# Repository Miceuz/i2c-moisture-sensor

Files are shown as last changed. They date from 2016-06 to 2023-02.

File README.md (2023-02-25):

# i2c-moisture-sensor

I2C based soil moisture sensor. A continuation of the [Chirp - plant watering alarm](https://github.com/Miceuz/PlantWateringAlarm) project. There is also an [RS485](https://github.com/Miceuz/rs485-moist-sensor) and an [analog](https://github.com/Miceuz/soil-moisture-sensor-analog) version available.



## I2C protocol
Available registers for reading and writing.

  Name | Register | R/W | Data length 
-------|----------|-----|-------------
GET_CAPACITANCE   | 0x00 | (r) | 2
SET_ADDRESS       | 0x01 | (w) | 1
GET_ADDRESS       | 0x02 | (r) | 1
MEASURE_LIGHT     | 0x03 | (w) | 0
GET_LIGHT         | 0x04 | (r) | 2
GET_TEMPERATURE   | 0x05 | (r) | 2
RESET             | 0x06 | (w) | 0
GET_VERSION       | 0x07 | (r) | 1
SLEEP             | 0x08 | (w) | 0
GET_BUSY          | 0x09 | (r) | 1

GET_BUSY returns 1 if any measurement is in progress, 0 otherwise.

## How to interpret the readings

16bit values are returned most significant byte first.

Both light and moisture sensors give relative values. Meaning, more moisture will give you higher reading, more light, lower reading. They are not calibrated to any particular si units - this is up to you.

Moisture is somewhat linear. I test all sensors before shipping and they give about 290 - 310 in free air at 5V supply.

Temperature is in Celsius, value is in tenths of degrees Celsius. I.e. value 252 would mean 25.2°C.

I didn't measure linearity of the light sensor, it gives 65535 in a dark room away form desk lamp. When it's dark, it takes longer to measure light, reading the light register while measurement is in progress will return the previous reading. Be aware, light sensor is pretty noisy.

Temperature is measured by the thermistor on the body of the sensor. Calculated absolute measurement accuracy is better than 2%. 

Note Upon reading the moisture or temperature value, a value form the previous read command is returned and the new measurement is started. If you do rare measurements and want to act instantly, do two consecutive readings to get the most up to date data. Also you can read GET_BUSY register via i2c - it will indicate when the measurement is done. Basically the process goes like this: read from GET_CAPACITANCE, discard results, then read from GET_BUSY until you get '0' as an answer, then read form GET_CAPACITANCE again - the returned value is the soil moisture NOW.

### Python library for Raspberry Pi

*NOTE: if you experience problems on Raspberry Pi 3, slow down I2C bus speed by adding this line to /boot/config.txt:*
**dtparam=i2c1_baudrate=30000**

[Göran Lundberg](https://github.com/ageir) has released a Python library for Raspberry Pi: [https://github.com/ageir/chirp-rpi](https://github.com/ageir/chirp-rpi)
It has a very comprehensive documentation and covers a lot of functionality.

Some features:
* Uses a trigger function to trigger all enabled sensors. User selectable.
* Get soil moisture in percent (requires calibration) or capacitance value.
* Several temperature scales to choose from. Celcius, Fahrenheit and Kelvin.
* Offset to calibrate the temperature sensor.
* Measurement timestamps for all on board sensors.
* Built in support for changing the I2C address of the sensor.
* Deep sleep mode to conserve power.
* Calibration tool for soil moisture.

### Raspberry Pi examples

This is interface class provided by Daniel Tamm and Jasper Wallace
```python
#!/usr/bin/python
# cannot use python3 because smbus not working there
# Modified script from https://github.com/JasperWallace/chirp-graphite/blob/master/chirp.py
# by DanielTamm

import smbus, time, sys

class Chirp:
	def __init__(self, bus=1, address=0x20):
		self.bus_num = bus
		self.bus = smbus.SMBus(bus)
		self.address = address
    
	def get_reg(self, reg):
		# read 2 bytes from register
		val = self.bus.read_word_data(self.address, reg)
		# return swapped bytes (they come in wrong order)
		return (val >> 8) + ((val & 0xFF) << 8)

	def reset(self):
		# To reset the sensor, write 6 to the device I2C address
		self.bus.write_byte(self.address, 6)

	def set_addr(self, new_addr):
		# To change the I2C address of the sensor, write a new address
		# (one byte [1..127]) to register 1; the new address will take effect after reset
		self.bus.write_byte_data(self.address, 1, new_addr)
		# second request is required since FW 0x26 to protect agains spurious address changes
		self.bus.write_byte_data(self.address, 1, new_addr)
		self.reset()
		self.address = new_addr

	def moist(self):
		# To read soil moisture, read 2 bytes from register 0
		return self.get_reg(0)

	def temp(self):
		# To read temperature, read 2 bytes from register 5
		return self.get_reg(5)

	def light(self):
		# To read light level, start measurement by writing 3 to the
		# device I2C address, wait for 3 seconds, read 2 bytes from register 4
		self.bus.write_byte(self.address, 3)
		time.sleep(1.5)
		return self.get_reg(4)

	def __repr__(self):
		return "<Chirp sensor on bus %d, addr %d>" % (self.bus_num, self.address)

if __name__ == "__main__":
	addr = 0x20
	if len(sys.argv) == 2:
		if sys.argv[1].startswith("0x"):
			addr = int(sys.argv[1], 16)
		else:
			addr = int(sys.argv[1])
	chirp = Chirp(1, addr)

	print chirp
	print "Moisture\tTemperature\tBrightness"
	while True:
		print "%d\t%d\t%d" % (chirp.moist(), chirp.temp(), chirp.light())
		time.sleep(1)
```

This is another RasPi example provided by user *krikk*
```python
#!/usr/bin/python

#https://github.com/adafruit/Adafruit-Raspberry-Pi-Python-Code/tree/master/Adafruit_I2C
from Adafruit_I2C import Adafruit_I2C
from time import sleep, strftime
from datetime import datetime
deviceAddr = 0x20

i2c = Adafruit_I2C( deviceAddr, -1, False )

#to change adress
#i2c.write8( 1, 0x22 )

#reset sensor, we need this otherwise i get inconsistent light reading in the dark...
i2c.write8( deviceAddr, 0x06 )
sleep(5)

i2c.write8(deviceAddr, 3)
sleep(3)
light = i2c.readU16(4, False)
temp = i2c.readS16(5, False)/float(10)
moisture = i2c.readU16(0, False)
print "Temperature\tMoisture\tBrightness"
print str(temp) + ":" + str(moisture) + ":" + str(light)
```

### Arduino library
Ingo Fischer has written an Arduino library for the sensor, it has a couple of ready made examples: https://github.com/Apollon77/I2CSoilMoistureSensor 

Below are old examples for bare-bones Arduino illustrating a basic I2C use.

### Arduino example
```arduino
#include <Wire.h>

void writeI2CRegister8bit(int addr, int value) {
  Wire.beginTransmission(addr);
  Wire.write(value);
  Wire.endTransmission();
}

unsigned int readI2CRegister16bit(int addr, int reg) {
  Wire.beginTransmission(addr);
  Wire.write(reg);
  Wire.endTransmission();
  delay(20);
  Wire.requestFrom(addr, 2);
  unsigned int t = Wire.read() << 8;
  t = t | Wire.read();
  return t;
}

void setup() {
  Wire.begin();
  Serial.begin(9600);
  writeI2CRegister8bit(0x20, 6); //reset
}

void loop() {
  Serial.print(readI2CRegister16bit(0x20, 0)); //read capacitance register
  Serial.print(", ");
  Serial.print(readI2CRegister16bit(0x20, 5)); //temperature register
  Serial.print(", ");
  writeI2CRegister8bit(0x20, 3); //request light measurement 
  Serial.println(readI2CRegister16bit(0x20, 4)); //read light register
}
```
### Note for ESP8266 based systems
In some cases the default ESP8266 Arduino I2C library has the clock stretching timeout set too low. If you experience intermittent communication, add this to your code:
```
Wire.setClockStretchLimit(2500)
```
### Micropython
Micropython library is available here: [https://github.com/scopelemanuele/pyChirpLib](https://github.com/scopelemanuele/pyChirpLib)

## Address change example
By default the sensor comes with 0x20 set as an address, this is an example on how to change address for indivitual sensor:
```arduino
#include <Wire.h>
 
void writeI2CRegister8bit(int addr, int reg, int value) {
  Wire.beginTransmission(addr);
  Wire.write(reg);
  Wire.write(value);
  Wire.endTransmission();
}
 
void writeI2CRegister8bit(int addr, int value) {
  Wire.beginTransmission(addr);
  Wire.write(value);
  Wire.endTransmission();
}
 
void setup() {
  Wire.begin();
  Serial.begin(9600);
                                       //talking to the default address 0x20
  writeI2CRegister8bit(0x20, 1, 0x21); //change address to 0x21
  writeI2CRegister8bit(0x20, 6);       //reset
  delay(1000);                         //give it some time to boot
}
 
/*loop scans I2C bus and displays foud addresses*/ 
void loop()
{
  byte error, address;
  int nDevices;
 
  Serial.println("Scanning...");
 
  nDevices = 0;
  for(address = 1; address < 127; address++ )
  {
    // The i2c_scanner uses the return value of
    // the Write.endTransmisstion to see if
    // a device did acknowledge to the address.
    Wire.beginTransmission(address);
    error = Wire.endTransmission();
 
    if (error == 0)
    {
      Serial.print("I2C device found at address 0x");
      if (address<16)
        Serial.print("0");
      Serial.print(address,HEX);
      Serial.println("  !");
 
      nDevices++;
    }
    else if (error==4)
    {
      Serial.print("Unknow error at address 0x");
      if (address<16)
        Serial.print("0");
      Serial.println(address,HEX);
    }    
  }
  if (nDevices == 0)
    Serial.println("No I2C devices found\n");
  else
    Serial.println("done\n");
 
  delay(5000);           // wait 5 seconds for next scan
}
```
### Particle Photon

There is a great [tutorial](ParticlePhoton-tutorial.md) by Miriam Cox for Particle Photon boards. Also there is a [library available](https://github.com/VintageGeek/I2CSoilMoistureSensor) by Mike.

## Links and mentions

* A [video from Growing Robot](https://www.youtube.com/watch?v=rB4vS7I0euA) about using the sensors with Raspberry Pi
* A [complete Open Source logging solution](https://git.jeelabs.org/jcw/zelkova) employing a batch of 40 sensors in Crete for tree monitoring
* [Chirp - Wemos - Azure bridge](https://github.com/korpiq/chirp-wemos-meter) ESP8266 based system that pushes sensor data to Azure cloud serivices.

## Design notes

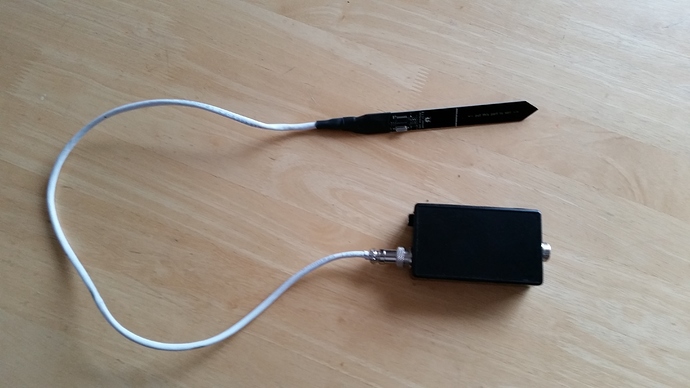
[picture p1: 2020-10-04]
pics/esp-8266-.jpg

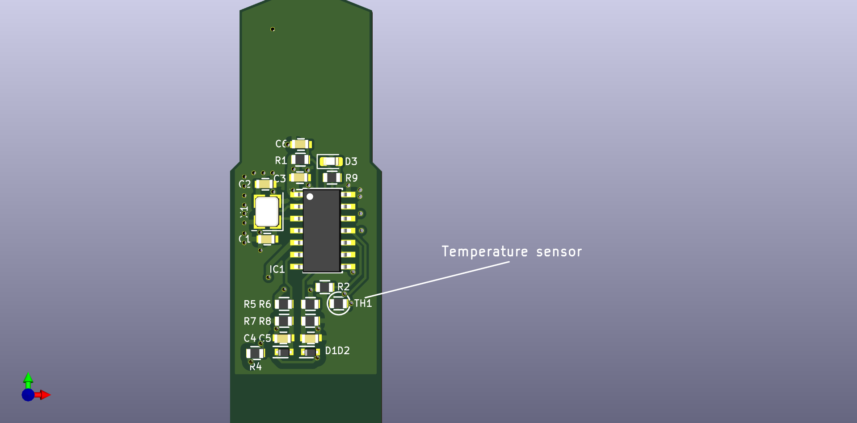
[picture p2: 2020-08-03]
temp-sensor-position.png

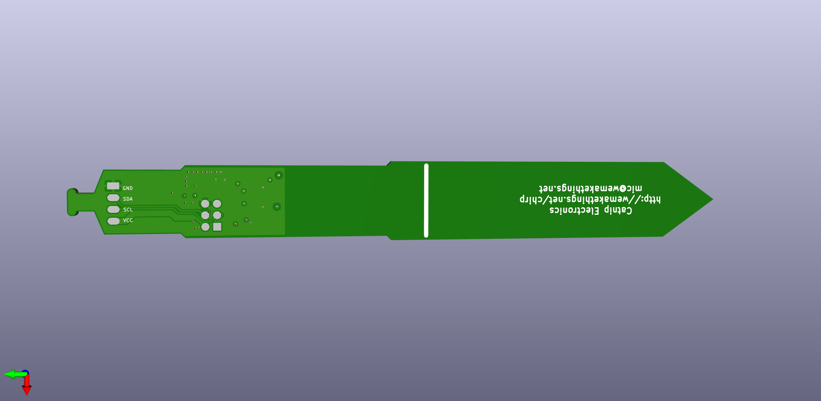
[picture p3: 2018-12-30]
i2c-moist-sensor.png

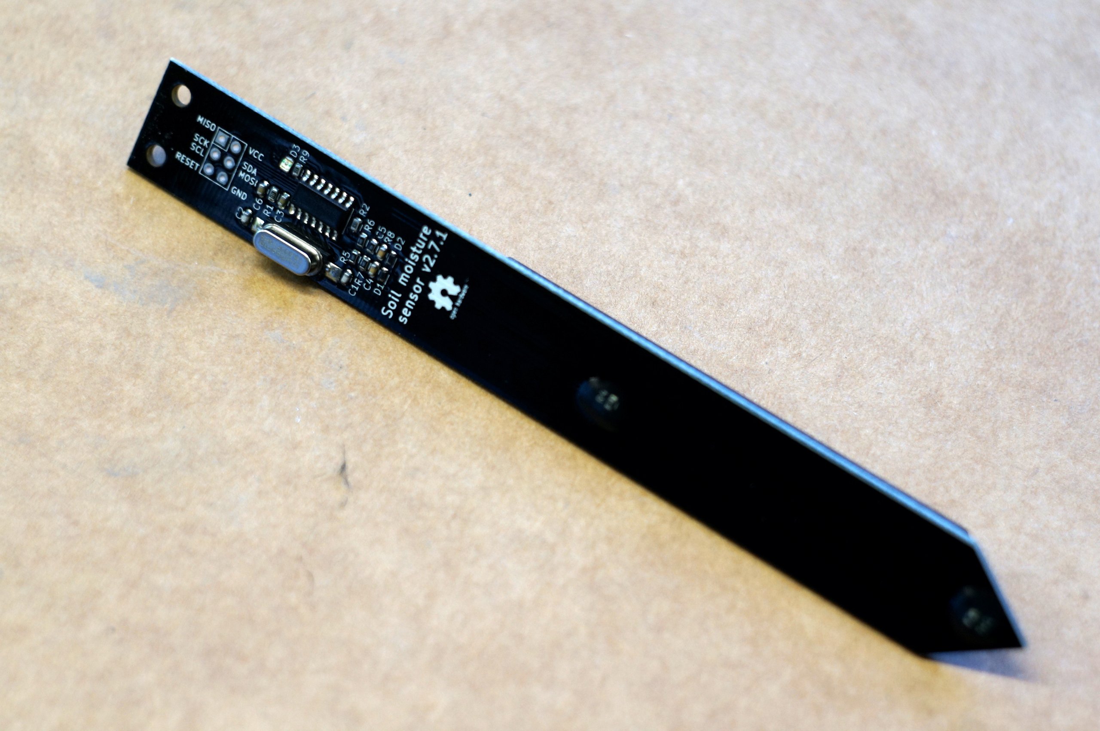
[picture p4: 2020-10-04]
pics/i2c-sensor-v2.7.1.jpg

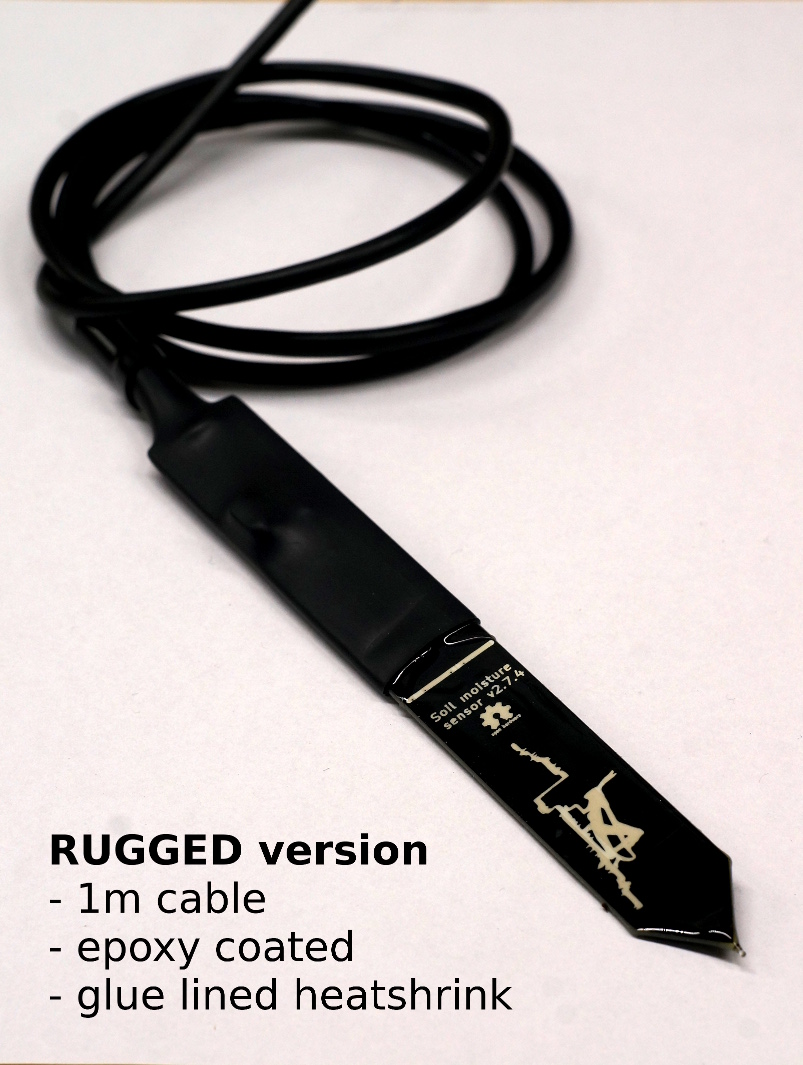
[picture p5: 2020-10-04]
pics/rugged.jpg

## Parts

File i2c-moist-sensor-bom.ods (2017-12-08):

ID | Designator | Value | Qty | FarnellID | Manufacturer | Mfg # | Replacement options
1 | IC1 | Attiny441 | 1 | 2396717 | ATMEL | ATTINY441-SSU | Exact part as specified
2 | D1, D2 | RB521S30T1G | 2 | 2322476 | FAIRCHILD SEMICONDUCTOR | BAT54XV2 | Exact part as specified
3 | TH1 | NCP18XH103F03RB | 1 | 2456122 | MURATA | NCP18XH103F03RB | Exact part as specified
4 | R1 | 10k | 1 | 2379939 | PANASONIC ELECTRONIC COMPONENTS | ERJ3RBD1002V | Any 10k resistor
5 | R2 | 10k 0.5% | 1 | 2379939 | PANASONIC ELECTRONIC COMPONENTS | ERJ3RBD1002V | Exact part as specified
6 | X1 | 16MHz | 1 | 2395958 | MULTICOMP | MCRSD16000F183000RR | Exact part as specified
7 | C1, C2 | 33pF | 2 | 2310585 | MULTICOMP | MC0603N330J500CT | Any 33pF capacitor
8 | R4, R9 | 330R | 2 | 2446656 | MULTICOMP | MCWR06X3300FTL | Any 5% 330R resistor
9 | C3, C6 | 1u 10V | 2 | 2310637 | MULTICOMP | MC0603X105K100CT | Any 1u capacitor
10 | C4, C5 | 1n | 2 | 2310598 | MULTICOMP | MC0603B102K500CT | Any 1n capacitor
11 | R5, R6, R7, R8 | 1M | 4 | 2446602 | MULTICOMP | MCWR06X1004FTL | Any 1M resistor
12 | D3 | KP-1608SURCK | 1 | 2449786 | KINGBRIGHT | KP-1608SURCK | Any 2V Vf 0603 LED
13 | HEATSHRINK |  | 1 |  |  | CB-DWT16-4X/1M-BK

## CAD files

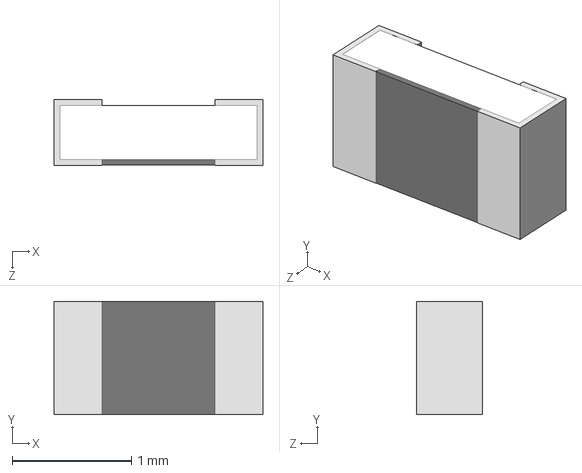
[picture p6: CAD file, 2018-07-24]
3d/User Library-RES_SMD-1.STEP
1.75 x 0.95 x 0.55 mm

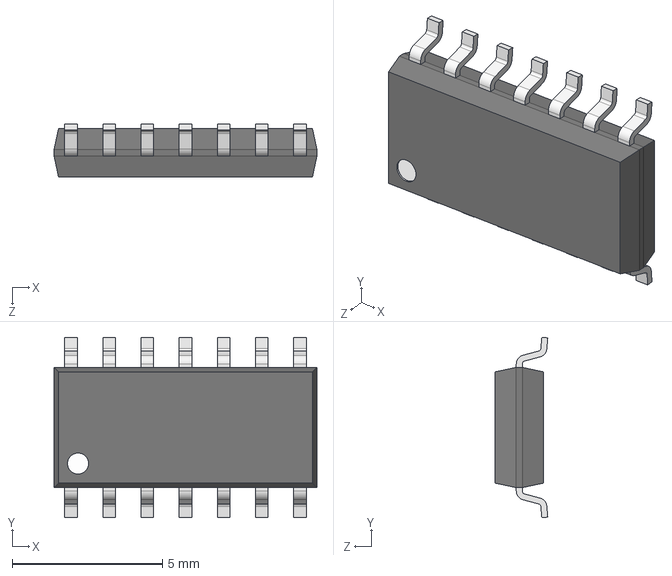
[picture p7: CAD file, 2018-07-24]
3d/User Library-SOIC-14.STEP
8.75 x 6.00 x 1.75 mm

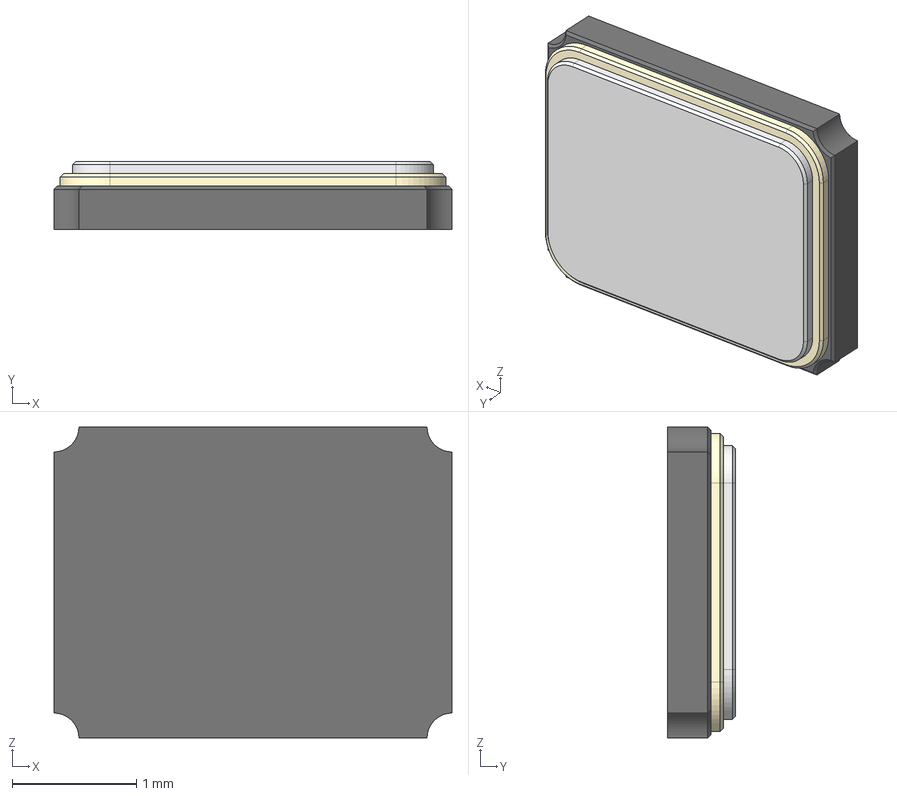
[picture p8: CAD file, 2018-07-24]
3d/CRY_SMD3225.STEP
3.20 x 0.55 x 2.50 mm

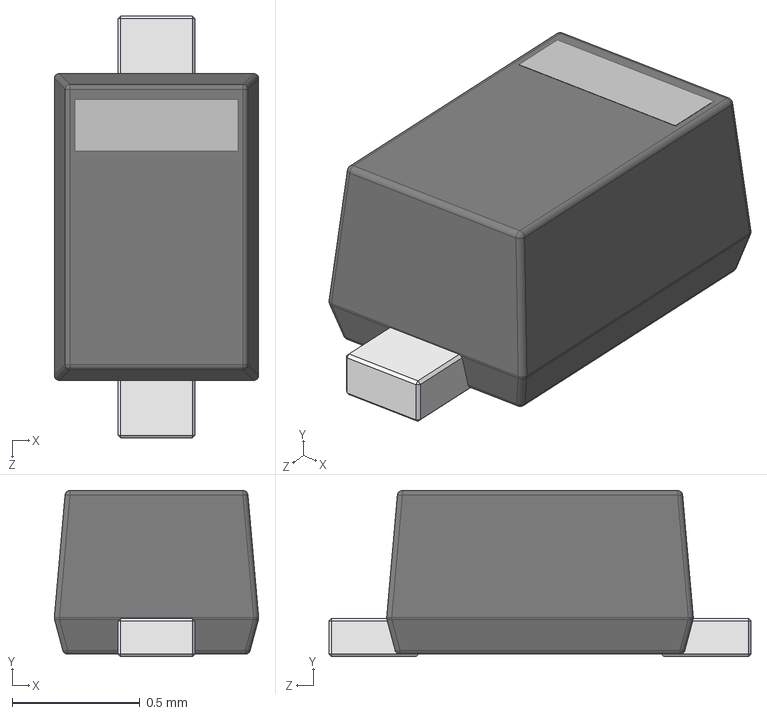
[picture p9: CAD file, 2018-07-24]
3d/User Library-SOD523-2.STEP
0.8 x 0.651 x 1.65 mm

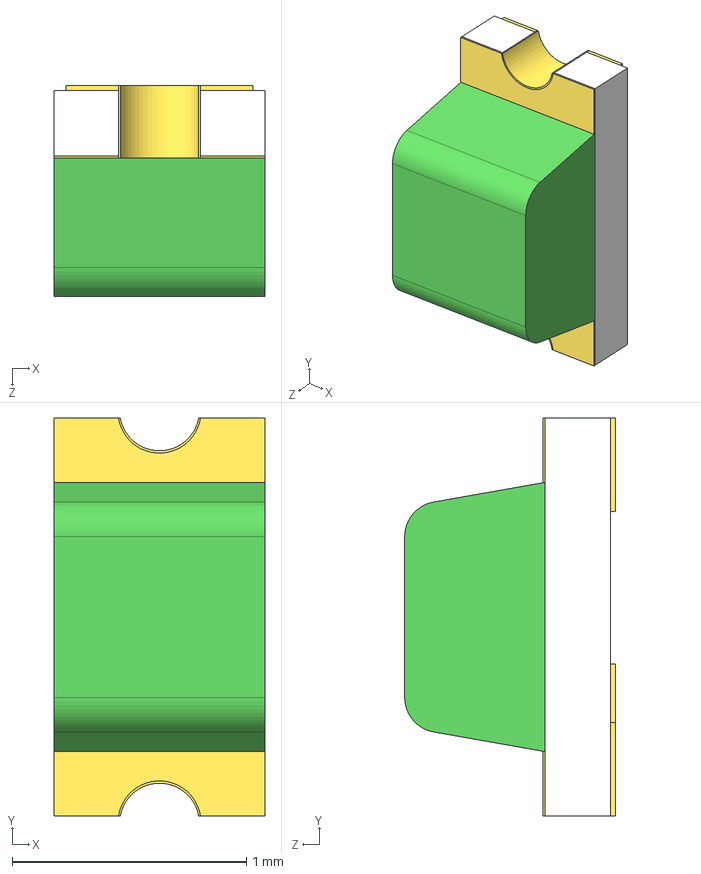
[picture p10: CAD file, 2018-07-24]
3d/User Library-LTST-C190GKT.STEP
0.9 x 1.70 x 0.9 mm
User Library-LTST-C190GKT_Pad005
User Library-LTST-C190GKT_Pad001
User Library-LTST-C190GKT_Pad004
User Library-LTST-C190GKT_Pad003
User Library-LTST-C190GKT_Lens
User Library-LTST-C190GKT_Pad

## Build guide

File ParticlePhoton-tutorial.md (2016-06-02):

Getting sensor to work with Particle Photon
===========================================
by Miriam Cox

As someone completely new to electrical work and to Particle microcontrollers, I hit a few slight hurdles in trying to convert this. For anyone else interested in how I got the sensor working with a Particle Photon, it's pretty simple:

**1) STARTING YOUR PROJECT**
Copy the example code into a "New App" in your Particle.io web IDE. You can name it whatever you'd like. Make sure you ALSO have your Particle Photon microcontroller registered to your Particle account so that you can flash the project onto it.

**2) ADDING A LIBRARY**
Create a new file inside this new app, then name it according to the library you are using (I eventually used Apollon77's code, as suggested by Miceuz) and copy the appropriate code from its git repo into these new files. Don't forget to include the library in your app's main file using the following syntax:
#include "NameOfLibraryFile.h"

_Note: As of this writing, it is also possible to fork this repo and rewrite it for import as a library into your Particle app, but that is a bit more work._

**3) INCLUDES**
In any library or example files you added to your project, strip out "define if/else" statements and their contents, then replace them with the following line (which will add Wire library and device functionality):
**#include "Particle.h"**

Flash your Photon with this app. Assuming you are successful (and assuming you also have the particle software installed on your computer) you can then open up a command line prompt on your computer and enter this command to view the serial monitor output from the Photon:
**particle serial monitor**

**4) SOLDERING**
For prototyping, I unplugged the Photon (which had headers), then popped it onto a breadboard. Then I stripped some jumper wires and soldered them directly to the I2C sensor's SCK/SCL line, VCC line, GND line, and SDA/MOSI line.

Obviously, you need to connect the Photon to your sensor; so to take advantage of the I2C capabilities of the Photon, you'll need to connect the Photon's D1 input to the sensor's SCK/SCL (clock) output, and then connect the Photon's D0 input to the sensor's SDA (data) output on the breadboard. Connect the sensor's VCC line and the Photon's 3V3 (power) input together on the breadboard. Then connect the sensor's GND line and the Photon's GND (ground) lines together on the breadboard.

**VERY IMPORTANT:** You will also need "pull up resistors" on the clock and the data lines; initially, I had NO IDEA what this meant, but, it turns out you'll just connect those lines into the power line using a resistor. All I had to do was grab a resistor and connect one leg of it to the SDA/MOSI-D0 line via the breadboard, then the other leg to the VCC-3V3 (power) line on the breadboard. Then I did the same for the clock, connecting one leg of the resistor to the SCK/SCL-D1 line and the other to the VCC-3V3 line.

_Note: in my case, all I had were 200 ohm resistors, and these at least got my project working. If you don't have any resistors connected, then your particle serial monitor won't even recognize that the I2C sensor is connected. Readings on the web suggest that ideally, you should use somewhere between a 4.7k ohm and 10k ohm resistor for each pull up, to help prevent "drift" on your readings, but someone more electrically inclined than myself could explain/clarify this._

I hope this helps! This sensor is absolutely FANTASTIC, by the way. Very sensitive (which I like), uses capacitive reading (which is much more accurate), and easy to use. Happy DIYing, friends!

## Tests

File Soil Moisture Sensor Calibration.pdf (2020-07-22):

I2C Soil Moisture Sensor Calibration (Catnip Electronics)
Converting the raw capacitance values of the soil moisture sensors to dry basis moisture content (%) of the soil

Materials and Methods

- Soil moisture sensor was powered at 3V3,
- Soil sample was collected from the field (Niato),
- Soil sample was sieved (2 mm) and cleaned from stones and roots,
- Soil sample was placed in the oven at 105oC for 24 hours,
- After 24 hours, when the soil was completely oven dried, the soil sample was removed from the oven and placed in an aluminum disk (23x17x6 cm),
- The weight of the empty disk and the dry soil were measured on an analytical balance,
- Three soil moisture sensors were buried in the soil,
- The aluminum disk containing the dry soil and the three soil moisture sensors was placed on an analytical balance,
- The sample weight (aluminum disk containing the dry soil and the three soil moisture sensors) was recorded,
- The raw capacitance values from the three soil moisture sensors were also recorded (completely dry soil),
- Distilled water was added to the dry soil until full saturation. Water was added evenly throughout the aluminum disk. This is critically important to ensure that moisture is thoroughly and evenly spread through the entire sample and not clumped at the surface or some other location (Picture 1),
- Balance readings of the sample weight (aluminum disk containing the wet soil and the three soil moisture sensors) and the raw capacitance values from the three soil moisture sensors were recorded simultaneously at an interval of 30 minutes for 26 days at room temperature (Picture 2),

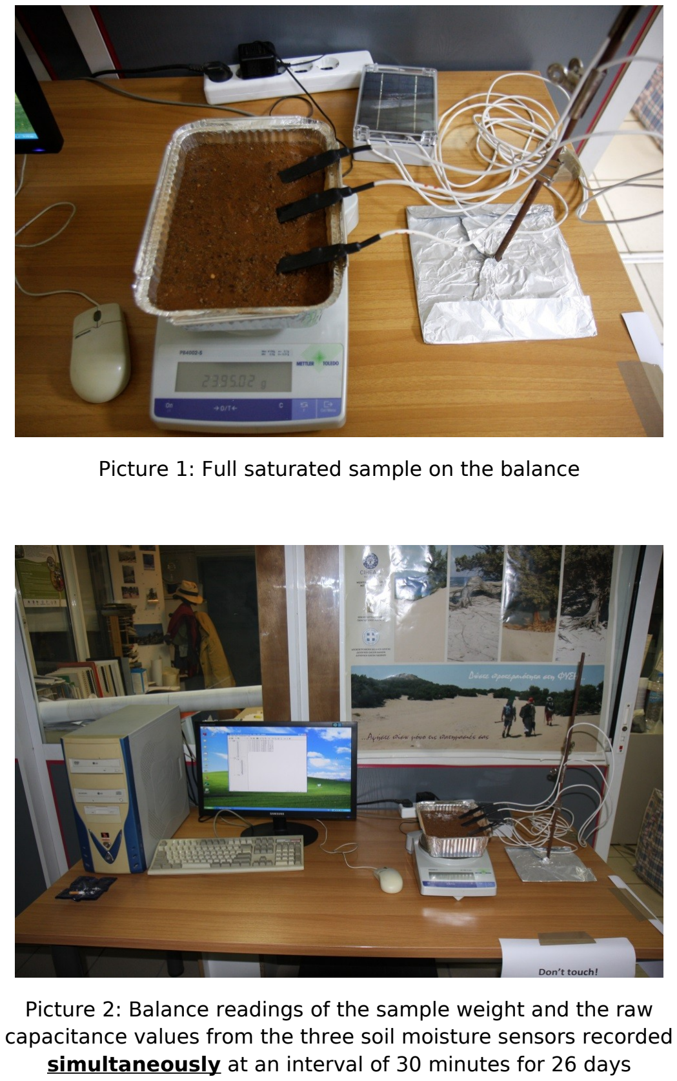
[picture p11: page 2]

Picture 1: Full saturated sample on the balance

Picture 2: Balance readings of the sample weight and the raw capacitance values from the three soil moisture sensors recorded simultaneously at an interval of 30 minutes for 26 days

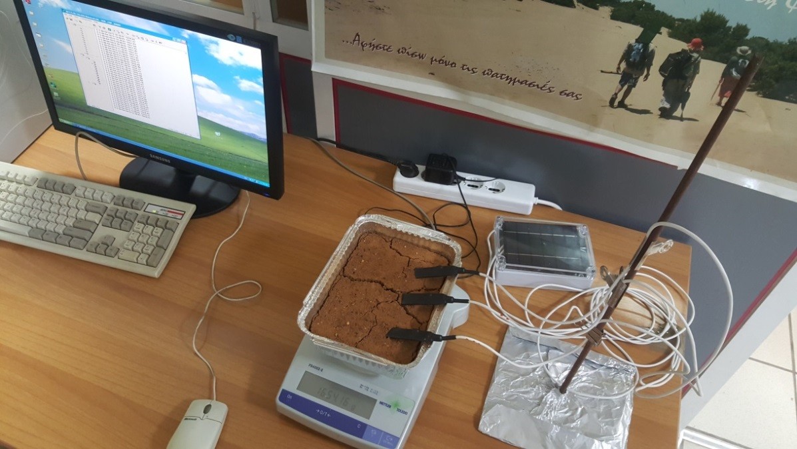
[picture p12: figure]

Picture 3: Dry sample after 26 days - balance readings of the sample weight and the raw capacitance values from the three soil moisture sensors recorded simultaneously at an interval of 30 minutes

- The real dry basis moisture content (MCd) of the soil sample at 30 minutes interval was calculated as:

MCd = (Wet soil weight – Dry soil weight) / Dry soil weight

- Having the real dry basis moisture content of the soil sample and the readings of its corresponding raw capacitance values from the three soil moisture sensors (30 minutes interval), the following 2
nd

order polynomial equation was developed using regression analysis in Excel:
MCd = (0.000001007*X²
)+(0.000024885*X)-
0.062508722

Where MCd is the calculated dry basis moisture content of the soil sample and X is the average readings of the soil moisture sensors.

SUMMARY OUTPUT

Regression Statistics
Multiple R | 0,997707255
R Square | 0,995419766
Adjusted R Square | 0,995410093
Standard Error | 0,007208576
Observations | 950

ANOVA
| df | SS | MS | F | Significance F
Regression | 2 | 10,69467422 | 5,347337 | 102905,5 | 0
Residual | 947 | 0,049209503 | 5,2E-05
Total | 949 | 10,74388372
| Coefficients | Standard Error | t Stat | P-value | Lower 95% | Upper 95% | Lower 95,0% | Upper 95,0%
Intercept | -0,062508722 0,005054067 | -12,368 | 1,12E-32 | -0,072427189 | -0,052590256 | -0,072427189 | -0,052590256
X | 0,000024885 | 2,43462E-05 | 1,022122 | 0,306984 | -2,2894E-05 | 7,26635E-05 | -2,2894E-05 | 7,26635E-05
X
2 | 0,000001007 | 2,7467E-08 | 36,67815 | 5,5E-184 | 9,53536E-07 | 1,06134E-06 | 9,53536E-07 | 1,06134E-06

Figure 1: Excel summary output of the regression

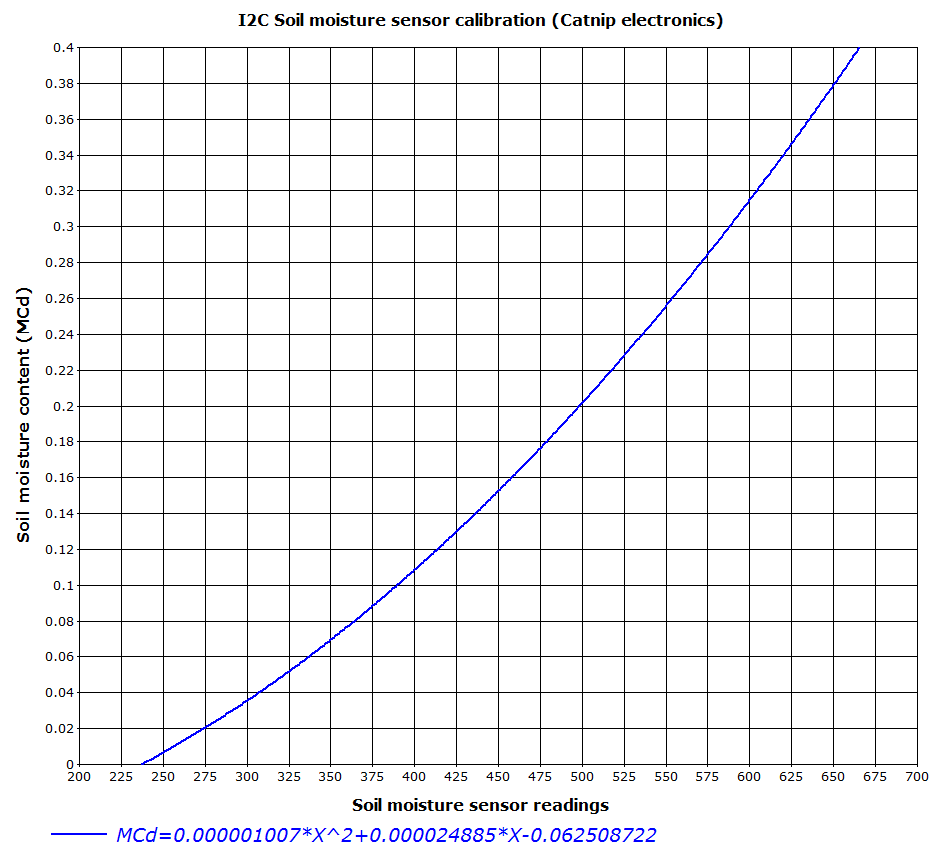
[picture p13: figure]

Figure 2: Graph of the polynomial equation

The developed equation can be used in Excel using the following formula:

=(0,000001007*A2^2)+(0,000024885*A2)-0,062508722

Where A2 is the cell containing the soil moisture sensor raw capacitance reading

Example:

The calculated dry basis moisture content (MCd) of the soil when a soil moisture sensor reads a capacitance value of 550 corresponds to:

MCd = (0.000001007*550²

)+(0.000024885*550)-0.062508722

MCd = 0.2558 or 25.58 %

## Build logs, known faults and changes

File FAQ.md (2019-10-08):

# Frequently asked questions

**Do you have the exact dimensions, or even better a CAD drawing of the sensor in 3D?**

Sensors are 18mm x 149mm. Zipped step file is available in github repository.

**How to set up multiple sensors connected to one Arduino Uno?**

You can connect several sensors to a single I2C bus. Exact maximum amount depends on many factors, mostly on the wiring length. To have several sensors working on a bus, you have to assing an individual address to each sensor. To do that, connect each sensor one by one and run an address change routine. Code is available as [an example](https://github.com/Apollon77/I2CSoilMoistureSensor/blob/master/examples/ChangeSensorI2CAddress/ChangeSensorI2CAddress.ino) of Arduino library. Raspberry Pi example is also [available](https://github.com/ageir/chirp-rpi#advanced-example-with-address-change-ability-and-calibration).

**Can I use a X meter long cable without affecting the sensor measurements?**

It depends. Note that I2C bus is not ment to run on cables, so it's a hack already. Nevertheless, a lot of products do this. I suggest reading online resources about running I2C on long cables to get some background information, but generally, to support long cables and ensure robust communication you can do the following: 
 * lower pullup resistor value, calculation is a bit complicated, but it seems you can go as low as 1k. More info [here](https://electronics.stackexchange.com/questions/1849/is-there-a-correct-resistance-value-for-i2c-pull-up-resistors).
 * slow down I2C speed. Consult your controller board documentation on how to do that
 * Use shielded cable
 
**How to solder wire to the sensor?**

Do not solder wires to the 6 pad connector - this is a programming header. Solder to 4 pads marked VCC, SCL, SDA, GND at the edge of the board. I suggest using a shielded 4 wire cable designed for security signalization installations. Do not solder the shield to the sensor, but ground it at the controller board side. Fix cable to the board using zip tie. Cover the wire connection and SMD parts with **glue-lined** heatshrink. Do not use a simple heatshrink as it will eventually let water in and will not allow it to evaporate resulting in short sensor lifetime.

**Do you offer the source code from the i2c chrip project? Can I reflash firmware of the sensor?**

Yes, sure, the sensor is open source hardware, all the code and hardware files are available on the [github page](https://github.com/Miceuz/i2c-moisture-sensor). You can use 6 pad header to program it using any AVR programming hardware like TinyISP, UsbAsp and similar. Also, you can use your [Arduino board as an AVR ISP programmer](https://www.arduino.cc/en/Tutorial/ArduinoISP).
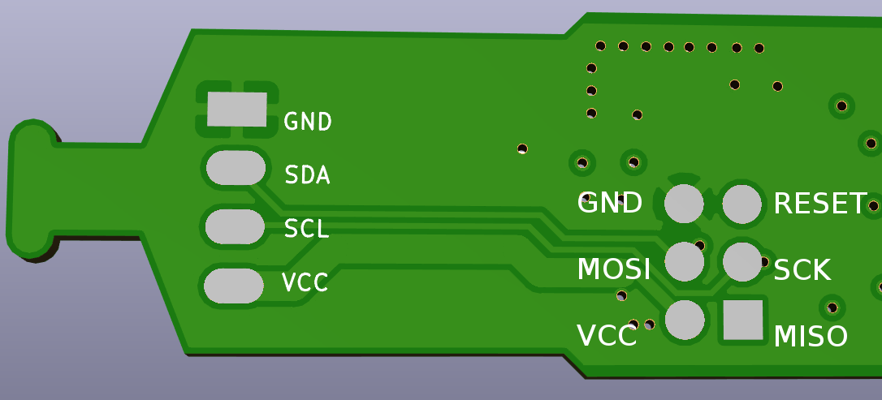
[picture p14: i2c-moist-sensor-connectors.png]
connectors


**Communication with ESP8266-based systems is unreliable, sensor sends data then stops working.**

In depth technical analysis is [available here](https://github.com/Apollon77/I2CSoilMoistureSensor/issues/8#issuecomment-295715953).

Add this call after you initialize I2C bus:
```
  Wire.setClockStretchLimit(4000); 
```

**How durable are non-rugged sensors?**

Standard solder mask seems to last about 3 months before flaking off. It really depends on the type of your soil and how often do you remove and insert the sensor as scratches will damage the surface and shorten the lifespan. I have had sensors working flawlessly for over a year in the flower pot at home when not disturbed. Note that you **must** protect sensor electronics with **glue-lined** heatshrink if you are going to install it outdoors. I use [this heatshrink](https://www.tme.eu/en/details/cb-dwt16-4x_1m-bk/heat-shrink-tubes/cyg/cb-dwt4x-160/) but you can use any similar one.

**Can you set different address for each sensor before shipping?**

Yes I can for orders of 50pcs or more, please drop me an email - mic at wemakethings net

## Rugged sensors

**How do I connect the sensor to my board?**

Wire colors go like this:
 * RED - VCC
 * BLACK - GND
 * BLUE or GREEN- SDA
 * YELLOW - SCK 

You can leave the metal sheet and metal wire unconnected for a quick test, but connect it to GND for proper installation.

Please check if your controller board has onboard pullup resistors for I2C. You need to add pull up resistors to both SCL and SDA lines if they are not there. Raspberry Pi has pullups onboard, Arduino UNO does not.

**What is the expected life of the rugged sensor for continuous use outdoor?**

I still don't have enough data to answer this question. Rugged sensors should be in practice indestructable, but failures sometimes happen. If you are using rugged sensor please let me know about the failures you experience. 

**Light sensor of rugged variant?**

Light sensing does not work for rugged sensors as light sensor is covered by heatshrink.

**I would like to have sensors with a cable up to X meters**

Sometimes I can provide customization for orders over 50 pcs, please drop me an email - mic at wemakethings net.

## Miscelaneous

**Can you provide a formal EU invoice?**

Yes, I can, please contact me directly via email - mic at wemakethings net

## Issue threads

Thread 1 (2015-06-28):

Can it be used outdoor ?

txaj, 2015-06-28:
Or even buried 5-6 cm underground ?

(I'm sorry to open an issue to ask a question but I couldn't find any way to contact you without registering on tindie)

Miceuz, 2015-06-29:
You would want to  cover in additional protection the place where cable
is soldered to the sensor, some people are putting a tube over the
electronics and pouring epoxy or silicone into it.

Regarding burying it underground - you would have to test this yourself
;) The answer would be "probabaly" after you pot it with above method.

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

--
mic.

dedekcz, 2020-04-16:
@Miceuz Nice project, Do You have any recommendation which epoxy is right one? is there any request for conductivity properties?

Miceuz, 2020-04-16:
You will get different reading with different kind of epoxy, but in general it does not matter al long as you calibrate after potting, make sure it's just non-conductive one, having no metal inside.

Closed 2015-06-29.

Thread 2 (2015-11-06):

strange reading on the light sensor & bugs in example code??

krikk, 2015-11-06:
hi!

i got your sensor running with a raspberry pi and after a lot of research and tries i got very good readings.. my raspberry pi code:

```
#!/usr/bin/python

#https://github.com/adafruit/Adafruit-Raspberry-Pi-Python-Code/tree/master/Adafruit_I2C
from Adafruit_I2C import Adafruit_I2C
from time import sleep, strftime
from datetime import datetime
deviceAddr = 0x20

i2c = Adafruit_I2C( deviceAddr, -1, False )

#to change adress
#i2c.write8( 1, 0x22 )

#reset sensor, we need this otherwise i get inconsistent light reading in the dark...
i2c.write8( deviceAddr, 0x06 )
sleep(5)

i2c.write8(deviceAddr, 3)
sleep(3)
light = i2c.readU16(4, False)
temp = i2c.readS16(5, False)/float(10)
moisture = i2c.readU16(0, False)
print str(temp) + ":" + str(moisture) + ":" + str(light)
```

... only strange thing i noted there was that i had to reset the sensor always before reading values, because otherwise i got strange readings from the light sensor after a few reads... have no clue why... buts that ok with me.

but now i got a shiny new arduino uno and i tried to run your sensor with it, and once again i get wrong readings from the light sensor, e.g. i get a negative reading when measuring in a dark room

i used the provided example code from github a adapted it:

```
void loop(){

    //Reset i2c moisture sensor
    Serial.println("Reset i2c moisture sensor");
    writeI2CRegister8bit(0x20, 6); //reset
    delay(5000);

    writeI2CRegister8bit(0x20, 3); //request light measurement
    delay(3000);
    int light = readI2CRegister16bit(0x20, 4); //read light register
    int moisture = readI2CRegister16bit(0x20, 0); //read capacitance register
    float temp = readI2CRegister16bit(0x20, 5)/(float)10; //temperature register
    char tempstr[15];
    dtostrf(temp,4, 1, tempstr);

    Serial.print("moisture: ");
    Serial.print(moisture);
    Serial.print(", Temp: ");

    Serial.print(tempstr);
    Serial.print(", Light: ");
    Serial.println(light);
    delay(2000);
}

void writeI2CRegister8bit(int addr, int value) {
    Wire.beginTransmission(addr);
    Wire.write(value);
    Wire.endTransmission();
}

unsigned int readI2CRegister16bit(int addr, int reg) {
    Wire.beginTransmission(addr);
    Wire.write(reg);
    Wire.endTransmission();
    delay(20);
    Wire.requestFrom(addr, 2);
    unsigned int t = Wire.read() << 8;
    t = t | Wire.read();
    return t;
}
```

 and i noted a few strange things in it:

```
unsigned int readI2CRegister16bit(int addr, int reg) {
...
}
```

why unsigned ?? ...what about negative temperature values (just tested with a cool-pack, give completely wrong values) (this works with my raspberry pi, python code)
also the example code does not wait 3 seconds with reading light value after writing...?

all in all the provided example code seems wrong to me... i reads values, but i think there is something wrong with the conversion of the values... would be nice if you could have a look into this  or give me some hints what i'm doing wrong... thx

Miceuz, 2015-11-13:
Hi,

I'm not exactly sure why you get weird readings. Are aware that light
measurement takes some time, if you query the sensor before reading is
done, it returns the old value. So basically you should wait for ~3 - 5
seconds before reading light measurement result.

Thanks for the code!

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

--
mic.

Apollon77, 2015-11-14:
I think you need an "Unsigned int" for the light reading ... then you will never get negaive values.

For Temperature it could work with "signed" values ... will test the next days ...

Apollon77, 2015-11-15:
I tested the sensor today in "cold" environment an git interesting "light" values - it seems that the light sernsor don't like cold :-)
I've put the sensor in my -14 degree celsius fridge ... each reading in the following list is 3 seconds delay:
At start of the test the values wew at around 236-238 capaticitance, 22,7 degree celsius and ligth around 25/26.000 as you see in the first values. Then I moved to the fridge and light was changig, but this is also not interesting. Look at the timepoint where temperature in falling ...

Soil Moisture Capacitance: 238, Temperature: 22.70, Light: 25833
Soil Moisture Capacitance: 236, Temperature: 22.70, Light: 26611
Soil Moisture Capacitance: 237, Temperature: 22.70, Light: 26522
Soil Moisture Capacitance: 237, Temperature: 22.70, Light: 26289
Soil Moisture Capacitance: 238, Temperature: 22.70, Light: 26027
Soil Moisture Capacitance: 236, Temperature: 22.70, Light: 29537
Soil Moisture Capacitance: 237, Temperature: 22.70, Light: 33503
Soil Moisture Capacitance: 237, Temperature: 22.80, Light: 33672
Soil Moisture Capacitance: 237, Temperature: 22.80, Light: 31238
Soil Moisture Capacitance: 237, Temperature: 22.60, Light: 16495
Soil Moisture Capacitance: 237, Temperature: 22.70, Light: 16924
Soil Moisture Capacitance: 237, Temperature: 22.50, Light: 18798
Soil Moisture Capacitance: 238, Temperature: 22.70, Light: 44514
Soil Moisture Capacitance: 237, Temperature: 22.70, Light: 29258
Soil Moisture Capacitance: 237, Temperature: 22.80, Light: 49732
Soil Moisture Capacitance: 238, Temperature: 22.70, Light: 59615
Soil Moisture Capacitance: 239, Temperature: 21.20, Light: 60379
Soil Moisture Capacitance: 239, Temperature: 19.40, Light: 62946
Soil Moisture Capacitance: 238, Temperature: 18.00, Light: 65221
Soil Moisture Capacitance: 239, Temperature: 16.80, Light: 2377
Soil Moisture Capacitance: 240, Temperature: 15.90, Light: 5015
Soil Moisture Capacitance: 240, Temperature: 14.70, Light: 7588
Soil Moisture Capacitance: 241, Temperature: 13.70, Light: 10411
Soil Moisture Capacitance: 241, Temperature: 12.90, Light: 13260
Soil Moisture Capacitance: 241, Temperature: 11.90, Light: 15969
Soil Moisture Capacitance: 241, Temperature: 11.00, Light: 19006
Soil Moisture Capacitance: 241, Temperature: 10.30, Light: 21965
Soil Moisture Capacitance: 242, Temperature: 9.40, Light: 24788
Soil Moisture Capacitance: 243, Temperature: 8.70, Light: 27819
Soil Moisture Capacitance: 242, Temperature: 7.90, Light: 30899
Soil Moisture Capacitance: 242, Temperature: 7.20, Light: 33837
Soil Moisture Capacitance: 244, Temperature: 6.50, Light: 36629
Soil Moisture Capacitance: 244, Temperature: 5.80, Light: 39785
Soil Moisture Capacitance: 244, Temperature: 5.20, Light: 42828
Soil Moisture Capacitance: 245, Temperature: 4.60, Light: 45913
Soil Moisture Capacitance: 245, Temperature: 3.90, Light: 48760
Soil Moisture Capacitance: 245, Temperature: 3.40, Light: 51619
Soil Moisture Capacitance: 245, Temperature: 2.70, Light: 54787
Soil Moisture Capacitance: 246, Temperature: 2.20, Light: 57772
Soil Moisture Capacitance: 246, Temperature: 1.60, Light: 60723
Soil Moisture Capacitance: 246, Temperature: 1.20, Light: 63549
Soil Moisture Capacitance: 247, Temperature: 0.60, Light: 1006
Soil Moisture Capacitance: 247, Temperature: 0.20, Light: 3900
Soil Moisture Capacitance: 247, Temperature: -0.30, Light: 6955
Soil Moisture Capacitance: 247, Temperature: -0.80, Light: 9639
Soil Moisture Capacitance: 248, Temperature: -1.30, Light: 12380
Soil Moisture Capacitance: 248, Temperature: -1.80, Light: 15314
Soil Moisture Capacitance: 247, Temperature: -2.30, Light: 17992
Soil Moisture Capacitance: 248, Temperature: -2.80, Light: 20789
Soil Moisture Capacitance: 248, Temperature: -3.00, Light: 23535
Soil Moisture Capacitance: 248, Temperature: -3.50, Light: 25958
Soil Moisture Capacitance: 249, Temperature: -4.10, Light: 28836
Soil Moisture Capacitance: 249, Temperature: -4.20, Light: 31497
Soil Moisture Capacitance: 249, Temperature: -4.60, Light: 33924
Soil Moisture Capacitance: 249, Temperature: -5.20, Light: 36519
Soil Moisture Capacitance: 249, Temperature: -5.30, Light: 38986
Soil Moisture Capacitance: 249, Temperature: -5.60, Light: 41580
Soil Moisture Capacitance: 249, Temperature: -6.00, Light: 44005
Soil Moisture Capacitance: 249, Temperature: -6.20, Light: 46106
Soil Moisture Capacitance: 250, Temperature: -6.60, Light: 48673
Soil Moisture Capacitance: 251, Temperature: -6.90, Light: 50834
Soil Moisture Capacitance: 251, Temperature: -7.30, Light: 53472
Soil Moisture Capacitance: 251, Temperature: -7.50, Light: 55486
Soil Moisture Capacitance: 251, Temperature: -7.90, Light: 57828
Soil Moisture Capacitance: 251, Temperature: -8.00, Light: 59703
Soil Moisture Capacitance: 251, Temperature: -8.30, Light: 62157
Soil Moisture Capacitance: 251, Temperature: -8.50, Light: 64149
Soil Moisture Capacitance: 251, Temperature: -8.80, Light: 624
Soil Moisture Capacitance: 252, Temperature: -8.90, Light: 2633
Soil Moisture Capacitance: 251, Temperature: -9.30, Light: 4599
Soil Moisture Capacitance: 252, Temperature: -9.40, Light: 6953
Soil Moisture Capacitance: 252, Temperature: -9.70, Light: 8264
Soil Moisture Capacitance: 252, Temperature: -9.80, Light: 7946
Soil Moisture Capacitance: 253, Temperature: -10.10, Light: 53029
Soil Moisture Capacitance: 252, Temperature: -9.30, Light: 27325
Soil Moisture Capacitance: 251, Temperature: -6.60, Light: 24511
Soil Moisture Capacitance: 251, Temperature: -4.50, Light: 11866
Soil Moisture Capacitance: 250, Temperature: -1.40, Light: 17357
Soil Moisture Capacitance: 249, Temperature: 1.20, Light: 65535
Soil Moisture Capacitance: 249, Temperature: 3.50, Light: 33331
Soil Moisture Capacitance: 247, Temperature: 4.20, Light: 30776
Soil Moisture Capacitance: 247, Temperature: 5.00, Light: 44845
Soil Moisture Capacitance: 247, Temperature: 6.10, Light: 40233
Soil Moisture Capacitance: 247, Temperature: 7.40, Light: 34273
Soil Moisture Capacitance: 245, Temperature: 7.80, Light: 32019
Soil Moisture Capacitance: 246, Temperature: 8.30, Light: 31617
Soil Moisture Capacitance: 247, Temperature: 8.80, Light: 31225
Soil Moisture Capacitance: 245, Temperature: 9.20, Light: 30780
Soil Moisture Capacitance: 246, Temperature: 9.50, Light: 30539
Soil Moisture Capacitance: 244, Temperature: 9.90, Light: 30480
Soil Moisture Capacitance: 245, Temperature: 10.30, Light: 30286
Soil Moisture Capacitance: 245, Temperature: 10.60, Light: 30011
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
Miceuz, 2015-11-17:
Weel, yes, light measurement is a hack that worked ok for room temperature operated devices ;) If you apply large temperature swings to the sensor, light measurement goes crazy as it depends on AVR pin leakage current and on parasitic capacitance in the LED.

Apollon77, 2015-11-17:
:-)) ok for me personally because I will not really use it, but should maybe be noted on the info-page ...

sekdiy, 2016-06-03:
Shouldn't the light counter top out at 65534 (2^16 - 1) instead of 65535 (2^16) in main.c, line 129 (https://github.com/Miceuz/i2c-moisture-sensor/blob/master/src/main.c#L129)?

I'd recommend to `#include <limits.h> ` and then use the `UINT_MAX` constant.

I've noticed this possibility after experiencing a discontinuity in my readings:

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

krikk, 2016-06-04:
i have a few sensors in testing now and all i can say is, that the light reading is a bit jumpy if it comes to low light conditions ... have a look on my graphs for 5 i2c-moisture-sensors and one BH1750 light sensor:
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
...i first thought resetting the sensor before each reading will get better results, but this is not the case...  we all know the light reading is a "hack" so i can live with it...

Miceuz, 2019-03-03:
To get the idea how does the light sensing work, please look for "led as light sensor" posts on hackaday and whatnot. The basic idea being that parasitic capacitance is charged when reverse-biasing it. Then this capacitance discharges in two ways - via pin leakage and via photo electric effect - more light shines into the led, faster it discharges. By timing this discharge event one can get an estimate of light level there is.

The method is very cheap, but very inaccurate - readings will depend wildly on ambient temperature and from sensor to sensor. Thus it is just suitable for rough estimate is it dark or not.

Closed 2019-03-03.

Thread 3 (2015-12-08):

Arduino Pull Up Resistors

SackLunch, 2015-12-08:
Do we need pull up resistors for an Arduino setup for pins A4 and A5 on the Arduino?  I have seen some comments on pages saying they are required but I'm not quite sure.

Any input appreciated.

Miceuz, 2015-12-08:
Yes, pullup resistors are to be provided by master.

SackLunch, 2015-12-09:
Thanks for the response.  I am having trouble running an I2C scanner and reading the Chirp!.  Works fine with other Arduino I2C products.  I've tried running 10k and 4.6k pull up resistors for Arduino A5 and A4 to 5 volts with similar results.  The scanner gets stuck and becomes non-responsive.
When I try to read the capacitance the serial prints out 65531 when running your example scripts.
Am I missing something obvious with my wiring?

Connection
Chirp pin 1 - no connection
Chirp pin 2 - Arduino VCC
Chirp pin 3 - Arduino A5 (with 4.6k jump up resistor)
Chirp pin 4 - Arduino A4 (with 4.6k jump up resistor)
Chirp pin 5 - no connection
Chirp pin 6 - Arduino GND

Miceuz, 2015-12-09:
What is your sensor version?

SackLunch, 2015-12-09:
I have version 2.4 with the reset button.

Miceuz, 2015-12-13:
Then you are using the wrong code. Use this: https://gist.github.com/Miceuz/8ace1cde27671e8e161d

gluckgabor, 2017-09-12:
Hi! I am using sensor version 2.7.5., ruggedized, with white cable. I have tried three different code versions and four different pullup resistors: 270Ohm, 4,5kOhm, 7,5kOhm and 10kOhm. I have almost exhausted all the possible combinations of these. All of these consistently gave the upper bound of the measurement interval at all three sensors no matter if the sensor was in cup of water or in dry air (ok, the light sensor is coated in waterproof rubber hose, so it is not legit measurement anyway). I would love take out the guesswork from the setup.. Can someone please give me a hint about the size of the pullup resistor I must use? Thank You in advance.

Miceuz, 2017-09-12:
Hi,

Probably your sensor is dead. Happens sometime. What was your order number? I will replace it for you. Also, can you send it back to me for analysis?

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

--
Sent from my Android device with K-9 Mail. Please excuse my brevity.

gluckgabor, 2017-09-12:
#79194, sure I will send it. Thank You!

gluckgabor, 2017-09-12:
Wrote to You on Tindie regarding your address. Thank You

Closed 2017-04-17.

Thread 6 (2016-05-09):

Getting this to work with Particle Photon Microcontrollers

marzipanic, 2016-05-09:
As someone completely new to electrical work and to Particle microcontrollers, I hit a few slight hurdles in trying to convert this. For anyone else interested in how I got the sensor working with a Particle Photon, it's pretty simple:

**1) STARTING YOUR PROJECT**
Copy the example code into a "New App" in your Particle.io web IDE. You can name it whatever you'd like. Make sure you ALSO have your Particle Photon microcontroller registered to your Particle account so that you can flash the project onto it.

**2) ADDING A LIBRARY**
Create a new file inside this new app, then name it according to the library you are using (I eventually used Apollon77's code, as suggested by Miceuz) and copy the appropriate code from its git repo into these new files. Don't forget to include the library in your app's main file using the following syntax:
#include "NameOfLibraryFile.h"

_Note: As of this writing, it is also possible to fork this repo and rewrite it for import as a library into your Particle app, but that is a bit more work._

**3) INCLUDES**
In any library or example files you added to your project, strip out "define if/else" statements and their contents, then replace them with the following line (which will add Wire library and device functionality):
**#include "Particle.h"**

Flash your Photon with this app. Assuming you are successful (and assuming you also have the particle software installed on your computer) you can then open up a command line prompt on your computer and enter this command to view the serial monitor output from the Photon:
**particle serial monitor**

**4) SOLDERING**
For prototyping, I unplugged the Photon (which had headers), then popped it onto a breadboard. Then I stripped some jumper wires and soldered them directly to the I2C sensor's SCK/SCL line, VCC line, GND line, and SDA/MOSI line.

Obviously, you need to connect the Photon to your sensor; so to take advantage of the I2C capabilities of the Photon, you'll need to connect the Photon's D1 input to the sensor's SCK/SCL (clock) output, and then connect the Photon's D0 input to the sensor's SDA (data) output on the breadboard. Connect the sensor's VCC line and the Photon's 3V3 (power) input together on the breadboard. Then connect the sensor's GND line and the Photon's GND (ground) lines together on the breadboard.

**VERY IMPORTANT:** You will also need "pull up resistors" on the clock and the data lines; initially, I had NO IDEA what this meant, but, it turns out you'll just connect those lines into the power line using a resistor. All I had to do was grab a resistor and connect one leg of it to the SDA/MOSI-D0 line via the breadboard, then the other leg to the VCC-3V3 (power) line on the breadboard. Then I did the same for the clock, connecting one leg of the resistor to the SCK/SCL-D1 line and the other to the VCC-3V3 line.

_Note: in my case, all I had were 200 ohm resistors, and these at least got my project working. If you don't have any resistors connected, then your particle serial monitor won't even recognize that the I2C sensor is connected. Readings on the web suggest that ideally, you should use somewhere between a 4.7k ohm and 10k ohm resistor for each pull up, to help prevent "drift" on your readings, but someone more electrically inclined than myself could explain/clarify this._

I hope this helps! This sensor is absolutely FANTASTIC, by the way. Very sensitive (which I like), uses capacitive reading (which is much more accurate), and easy to use. Happy DIYing, friends!

Miceuz, 2016-05-17:
Thanks a lot for this! I will incorporate this into the documentation for the project. How do I credit you? Name? Links to websites?

marzipanic, 2016-05-17:
You can just put my name, Miriam Cox, if you'd like. Thanks!

Closed 2016-06-02.

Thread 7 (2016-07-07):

Attiny getCapacitance wrong?

breemts, 2016-07-07:
Hi,
I wanted to "update" my sensor and see if it makes a difference. Now the capacitance reading is 1023-1025. I tried to figure out why and thats what I noticed.
**getCapacitance** returns this: `1023 - (caph - capl)` and on my sensor capl is higher than caph. So I wanted to know why. With my DMM I measured pin 6(PA7) wich should be capl, pin 8(PA5) should be caph and pin 5(PA2) wich isn't mentioned in the code but is connected to the sensor-traces.
pin6 _2.45V_; pin8 _2.46V_; and pin5 _2.43V_.
When I manipulate the code that I get capl and caph on my console capLow is alwasy _1-2_ values higher than caphigh. capl values are 508-506 and caph values are _507-504_.
So I thought my Sensor is broken, but what part? I measured all **components** and they are all **fine**.

Than I took another sensor that I have and measured the Voltage on the pins.
pin6 _4.88V_; pin8 _4.94V_; pin5 _4.85V_
I get readings about 230 from this sensor.

So could it be that the code for the Attiny is wrong? When I do the calculation with the formal in the code and use the values of the working sensor I get this: `1023 -(991[4.94V] - 979[4.88V]) = 1011`
So the working Sensor must have **different code**.
And I think the Voltage difference is because **PA2 the "Exitation" pin is not mentioned in the code**. I think it should be set to "HIGH" or _1024_, something like this.

Would be really nice if you could update your code. And what kind of **IDE** did you use for programming the Attiny? I'm uploading over a Arduino via ISP.

Best.
Benjamin Reemts

madmax76, 2016-11-07:
> And I think the Voltage difference is because PA2 the "Exitation" pin is not mentioned in the code. I think it should be set to "HIGH" or 1024, something like this.

Excitation is done by setting the CKOUT Fuse, see the Makefile. Did you check that? If I am not mistaken, the full 16MHz is put onto the sensor track via the 330Ohm resistor. I am currently investigating if it's possible to run without the external clock source (16MHz Crystal).

I have used both Atmel Studio as well as USBAsp with AVRdude to program the device.

Miceuz, 2016-11-07:
I can guarantee that the code on the github is the same one I use to program sensors. It is possible to run on internal RC oscillator, but the main reason of adding a crystal was improved stability - internal oscillator drifts a lot with ambient temperature.

Closed 2017-04-17.

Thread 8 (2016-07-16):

Suddenly weird reading?

solars, 2016-07-16:
Hi there,

I'm using the sensor with a Wemos D1 Mini, it worked nicely. After changing some code (not related to the sensor), I suddenly get readings:

Temperature: -0.10 (float temp = sensor.getTemperature()/(float)10;)
Light: 4294967295
Firmware version: FF
Sensor Address: 20

Can anyone tell me what went wrong?

Thank you,
Christoph

montreuilg, 2016-11-04:
I have the same problem, using the example code provided here!

I2C Soil Moisture Sensor Address: 20
Sensor Firmware version: FF
Soil Moisture Capacitance: 65535, Temperature: -0.10, Light: 65535
---------------------------------------------

solars, 2016-11-05:
Check if you are using the right pins, I think in my case I swapped them, but don't remember exactly..

gluckgabor, 2017-11-01:
Hi All,

I have the same problem. Can't figure out what is the issue. There are no special pins to be referenced in the code..  Care was taken to observe these 4, and pullup resistors are in place: RED - VCC, BLACK - GND, GREEN- SDA, YELLOW - SCL, it was working, then it suddenly wrong readings exactly same as the above reported ones..

mindforger, 2017-11-01:
maybe there is a chance to break the i2c on the attiny in some way by using odd timing (talk about edge cases) you can try to do a reset from your host controller by toggeling the SCL manually (open drain, so only set the output to low and toggle the direction of the pin) for a few times (at least 8, to clear off the shift register) ... or maybe toggle the power line through eitehr direct a port pin or using an transistor

BEWARE! always turn off the I2C master and set the SCL and SDA pins to low and output to prevent crossfeeding any power BEFORE turning off the VCC of the sensor to reset it!

gluckgabor, 2017-11-01:
Hi Mindforger!

Thank You for superfast reply.

I understand your instructions to be this steps:

1. Set the SCL and SDA pins to "low and output" and toggle the direction of these pins for at least 8 times to clear off the shift register.
2. Or toggle the VCC power line through both directions via a port pin.
3. Turn off the I2C master.
4. Turn off the VCC of the sensor to reset it.

Question now is how to still power the sensor after turning off the I2C master.. as the I2C master is supplying the sensor with VCC... I understand your warning so that I have to turn off the I2C master first and only after that I can turn off the sensor..

For the toggling I have written the following, is this what You meant? (My microcontroller type is Genuino Zero btw...)

pinMode(SCL, OUTPUT);
pinMode(SDA, OUTPUT);
digitalWrite(SCL, HIGH);   // sets  on
digitalWrite(SDA, HIGH);   // sets on
delay(200);                  // waits
digitalWrite(SCL, LOW);
digitalWrite(SDA, LOW);
delay(200);
digitalWrite(SCL, HIGH);   // sets on
digitalWrite(SDA, HIGH);   // sets on
delay(200);                  // waits
digitalWrite(SCL, LOW);
digitalWrite(SDA, LOW);
delay(200);
digitalWrite(SCL, HIGH);   // sets  on
digitalWrite(SDA, HIGH);   // sets on
delay(200);                  // waits
digitalWrite(SCL, LOW);
digitalWrite(SDA, LOW);
delay(200);
digitalWrite(SCL, HIGH);   // sets on
digitalWrite(SDA, HIGH);   // sets on
delay(200);                  // waits
digitalWrite(SCL, LOW);
digitalWrite(SDA, LOW);
delay(200);
digitalWrite(SCL, HIGH);   // sets  on
digitalWrite(SDA, HIGH);   // sets on
delay(200);                  // waits
digitalWrite(SCL, LOW);
digitalWrite(SDA, LOW);
delay(200);
digitalWrite(SCL, HIGH);   // sets  on
digitalWrite(SDA, HIGH);   // sets on
delay(200);                  // waits
digitalWrite(SCL, LOW);
digitalWrite(SDA, LOW);
delay(200);
digitalWrite(SCL, HIGH);   // sets on
digitalWrite(SDA, HIGH);   // sets on
delay(200);                  // waits
digitalWrite(SCL, LOW);
digitalWrite(SDA, LOW);
delay(200);
digitalWrite(SCL, HIGH);   // sets  on
digitalWrite(SDA, HIGH);   // sets on
delay(200);                  // waits
digitalWrite(SCL, LOW);
digitalWrite(SDA, LOW);
delay(200);
digitalWrite(SCL, HIGH);   // sets on
digitalWrite(SDA, HIGH);   // sets on
delay(200);                  // waits
digitalWrite(SCL, LOW);
digitalWrite(SDA, LOW);
delay(200);
pinMode(SCL, INPUT);
pinMode(SDA, INPUT);

Thank You in advance!

gluckgabor, 2017-11-01:
I have discovered that the erroneous data is displayed at the serial monitor even when the sensor is not connected... puzzles me more and more..

mindforger, 2017-11-01:
thats kind of normal, I2C is a Pull down Bus, it has a continous high level if not touched, all slaves and master only pull down, so there can never be a short circuit, if you are reading 0xFFFF this means, the slave did not respond to your read request and when it does not touch the line, that means you get 16 1-bits reading 0xFFFF or 65535 ... your issue is, that the slave maybe responds to your address byte (check if you get an acknowledge on the address byte) but does not shift out any data for whatever reason ... try to reduce the speed for testing, the sensor can adapt to all known I2C speeds as far aws i know

gluckgabor, 2017-11-01:
Seems like I2C address scanning solved the problem, found on this link: [http://playground.arduino.cc/Main/I2cScanner](http://playground.arduino.cc/Main/I2cScanner) However I am still puzzled how the I2C address of this slave have changed seemingly all by itself.. :)

Miceuz, 2017-11-01:
@gluckgabor Did you by any chance disconnect the sensor while the bus was running? Maybe connection was flaky? Sensors have this drawback - I did not add any protection on set address command and a stray communication on the bus can be interpreted as an address set command.

gluckgabor, 2017-11-01:
Yes, that is fully possible. Thanks for explanation! Have a nice day.

Closed 2016-11-05.

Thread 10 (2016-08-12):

Trigger external reset

pilotak, 2016-08-12:
Hi I'm using this sensor with with ESP8266 and it works perfectly @8MHz. I'm not using termistor and LED. Is there any chance you could provide me with a code to wake up on FALLING edge on PCINT9 and then trigger 10ms LOW on PA3 and then go to sleep again? I would use it to trigger reset on ESP and wake up when charger got connected.

Thank you
Pavel

Miceuz, 2016-08-16:
Hi,

Frankly, the code is there, go on and use it as you like, I don't provide support at this level, sorry.

pilotak, 2016-08-16:
That's fine. And if I pay, are interested?

Dne 16. 8. 2016 6:32 odpoledne napsal uživatel "Albertas Mickėnas" <
notifications@github.com>:

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

Closed 2016-08-16.

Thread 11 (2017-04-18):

Sensor outputs only 65535 as the reading

varunhr, 2017-04-18:
Hi i recently bought a chirp I2C soil moisture sensor V2.7.4 and i hooked it up to Arduino Uno Like this
Uno Chirp
5V/3.3V----- VCC(Tried Both)
Gnd---- GND
SDA -----SDA(10k Pullup)
SCL------ SCL(10k Pullup)

My Code is this
-----------------------------------------

#include <Wire.h>

void writeI2CRegister8bit(int addr, int value) {
Wire.beginTransmission(addr);
Wire.write(value);
Wire.endTransmission();
}

unsigned int readI2CRegister16bit(int addr, int reg) {
Wire.beginTransmission(addr);
Wire.write(reg);
Wire.endTransmission();
delay(20);
Wire.requestFrom(addr, 2);
unsigned int t = Wire.read() << 8;
t = t | Wire.read();
return t;
}

void setup() {
Wire.begin();
Serial.begin(9600);
writeI2CRegister8bit(0x20, 6); //reset
}

void loop()
{
Serial.print(readI2CRegister16bit(0x20, 0)); //read capacitance register
Serial.print(", ");
Serial.print(readI2CRegister16bit(0x20, 5)); //temperature register
Serial.print(", ");
writeI2CRegister8bit(0x20, 3); //request light measurement
Serial.println(readI2CRegister16bit(0x20, 4)); //read light register
delay(1000);
}

-----------------------------------------------------
My Serial port output is this

--------------------------------
65535, 65535, 65535
65535, 65535, 65535
65535, 65535, 65535
65535, 65535, 65535
65535, 65535, 65535
65535, 65535, 65535
--------------------------------

Miceuz, 2017-04-18:
Hi,

How long if your cable? Also, please write directly to me - mic at wemakethings net. Please send me your order number, we will sort it out.

varunhr, 2017-05-08:
Hi,
    Sorry for the delay in response. The sensor worked properly after some
solder touchup on the Crystal Oscillator. Thanks for your support.

Regards
Varun h r

On Sun, May 7, 2017 at 4:27 PM, Albertas Mickėnas <notifications@github.com>
wrote:

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

Closed 2017-05-07.

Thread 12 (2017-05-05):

low power usage

parallelpilgrim, 2017-05-05:
Is there any way you are aware of to get power usage while sleeping under 1.1mA?

I've been looking at some of the sleep code for hints but was wondering if anything like this was planned.

Ideally under 1mA would be ideal for sleep mode consumption. Additionally I only care about moisture readings.

thanks!

Miceuz, 2017-05-07:
Hi,

Yes, there is a sleep instruction you can issue via I2C. Then thermistor circuit dominates the power consumption - 20k @ 5V makes it 250uA, 20k @ 3.3V - 165uA. There is no way around this currently, but I will fix it in the next revision of the sensor. My experiments show that I can get as low as 2uA in deep sleep mode. But anyway, It will be well under 1mA in the current revision.

Closed 2017-05-07.

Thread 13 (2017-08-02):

Reading of getCapacitance() gets "historical data"

bilbolodz, 2017-08-02:
First reading of getCapacitance() provide "old data". To get current moisture reading you have to call getCapacitance() twice.

bilbolodz, 2017-08-02:
These issue should be open under "Arduino library" (https://github.com/Apollon77/I2CSoilMoistureSensor). My mistake sorry.

Closed 2017-08-02.

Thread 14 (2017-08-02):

Soil Moisture Capacitance depends on power supply voltage

bilbolodz, 2017-08-02:
Value returned by getCapacitance() depends on power supply voltage. In the same physical conditions (power supply "about" 3,3V) dry sensor:

- voltage 3,44 V ADC value 346
- voltage 3.28 V ADC value 366

You are using Vcc as analog reference (  ADMUXB = 0 in adcSetup() function). It's probably better to use "Internal 1.1V or 2.2 V" as reference for ADC

Miceuz, 2017-08-16:
Yes, it is true. You have to provide a stable voltage for the sensor. I have solved this in my [rs485](https://github.com/Miceuz/rs485-moist-sensor) sensor version by adding an on-board regulator, maybe I will pull this change to i2c sensor sometime.

bilbolodz, 2017-08-16:
My soil moisture sensors are battery powered. Adding on-board power regulator to such sensors it's just a waste of power and it's not a good idea. It should be corrected in software.

Miceuz, 2017-08-16:
Then you can provide regulation for all of the sensors at once. You are welcome to share the calibration table if you go the software route.

bilbolodz, 2017-08-16:
I'm using you sensor with "own build" Mysensors node with NFR24L01 transport as "main CPU". There are battery powered  and power regulator is not needed because there are powered directly from CR123 battery. Arduino and NRF24L01 are working good "down to" 2.8V voltage (actually there are working even at 1.8V if atmel is using internal 1MHz oscillator). I think you sensor also should work at 2.8V so that's why I'm asking to use internal 1.1V reference instead of external power supply.

Miceuz, 2017-08-16:
Yes, I could use internal 1.1V reference, but this creates some issues too - I need to generate the test square wave at 1.1V peak to peak then, this means, I have to create 1.1V source on board, add level shifting, buffering, etc - this adds to the price and my aim is to provide a cheap sensor.  I could use internal 2.2V reference and no level shifting, but then again, some ADC readings will be over the range when the battery is full and then I'm limited to 3V power only. Tradeoffs have to be made somewhere and I am making one which impacts the price the most.

BTW idea about using software compensation is really interesting and might work. Please share if you get any good results.

Lastly - this is an open source project, you can download the firmware and do whatever with it, also you can modify hardware.

In my next batch of sensors I have made a change that will really improve the battery life - I will be powering down thermistor divider circuit that now hogs the major part of power consumption in sleep - 150uA

bilbolodz, 2017-08-16:
OK, thank your for your statement. I will think if I'm able to deal with these issue in software way without modifying current hardware.

bilbolodz, 2017-08-19:
I think it could be good idea to add command to measure "system voltage". I requires to stop square wave give "0" measure SENSE_LOW, give "1" measure SENSE_HIGH and report it. That should allow to compute correction factor by main CPU (or even it could be corrected in sensors itself). No hardware modification is needed it also doesn't break backward compatibility with previous code.

Miceuz, 2017-08-23:
It is not how it works with ADC - you will get 0 and 1023 as readings because adc reference is system voltage. If I use internal reference, then system voltage is way above the reference, thus I need a hardware change - resistor divider to measure system voltage.

bilbolodz, 2017-08-23:
I know how ADC works. There is already 1:1 divider on the board (two 1M resistors). In case of 3V power supply it's enough to measure power voltage using 2.2V internal reference, in case of 5V it's problematic....The other issue is: is it usable information and is it possible to compute correction from it. I thought about it but got no solution so far.

Closed 2017-08-16.

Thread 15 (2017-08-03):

improve sensitvity

mindforger, 2017-08-03:
one thing in advance, i am not profesional in things like electronics but i talked to a co-worker beeing professional and asked him if i could probably get better sensitvity on this

he told me you could mirror the capacitor layout on both sides of the PCB and connect the planes with a few vias, this increases the overall capacity coupling over the surface and greatly reduces the coupling through the PCB material itself, resulting probably in an overall capacity loss but a great improvement on capacity change through the surface field

Miceuz, 2017-08-16:
Thanks for the tip! I am not sure if there really is any need for more sensitivity for now.

Closed 2017-08-16.

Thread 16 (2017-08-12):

Invalid data after some time

lobeck, 2017-08-12:
I've setup the sensor with a Adafruit Feather HUZZAH (ESP8266) and can read data for a while (1-3 days) then suddenly i only get 65k capacitance and invalid temperatures. The connections are soldered on a prototype board and 10k pull-ups

Power supply is a Anker wall adapter, so i don't think it's an issue.

Here's the relevant code (stripped the network pieces):

```
#include <ESP8266WiFi.h>
#include <WiFiUDP.h>
#include <I2CSoilMoistureSensor.h>
#include <Wire.h>

int status = WL_IDLE_STATUS;     // the Wifi radio's status
WiFiUDP udp;

I2CSoilMoistureSensor sensor;

void setup() {
  Wire.begin();
  Serial.begin(9600);

  Serial.println("Attempting to connect to WPA network...");
  udp.begin(4097);

  sensor.begin(); // reset sensor
  delay(1000); // give some time to boot up
  Serial.print("I2C Soil Moisture Sensor Address: ");
  Serial.println(sensor.getAddress(),HEX);
  Serial.print("Sensor Firmware version: ");
  Serial.println(sensor.getVersion(),HEX);
  Serial.println();
}

void loop() {
  while (sensor.isBusy()) delay(1000); // available since FW 2.3

  int capacitance = sensor.getCapacitance();
  float temperature = sensor.getTemperature()/(float)10;

  sensor.sleep(); // available since FW 2.3
  udp.beginPacket({192, 168, 2, 48}, 8089);

  Serial.print("Soil Moisture Capacitance: ");
  Serial.print(capacitance); //read capacitance register
  Serial.print(", Temperature: ");
  Serial.println(temperature); //temperature register

  udp.print(chirpLine);
  udp.endPacket();

  delay(10 * 1000);
}
```

Any ideas what might cause this? Currently testing a version without the `sensor.sleep()`, because i haven't found any statements regarding wakeup.

Miceuz, 2017-08-16:
Hi,

Probably it's a combination of long cable and esp8266 side treating clock stretching poorly. Have a look in this thread where we were debugging something similar to this:
https://github.com/Apollon77/I2CSoilMoistureSensor/issues/8

lobeck, 2017-08-16:
Haven't seen Apollon77/I2CSoilMoistureSensor#8 as relevant in my case, as i only got the issue after some time. Got the rugged version too, so cable length wouldn't be my fault ;) It's currently mitigated by not using `sensor.sleep()`, but maybe i'll move away from the esp8266 too and move to some other low power solution. Without the sleep it's running now for 5 days and i'll further look into this once it's happening again.

Closed 2017-08-16.

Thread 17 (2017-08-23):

Trouble getting reading from Chirp! with Raspberry PI

dpassarella, 2017-08-23:
Hi,  I have 2 Chirp!s and I can't get them to give meaningful readings from the Raspberry Pi.  I have them wired like this

I am using the following code from your github readme

import smbus, time, sys

class Chirp:
def init(self, bus=1, address=0x20):
self.bus_num = bus
self.bus = smbus.SMBus(bus)
self.address = address

def get_reg(self, reg):
	# read 2 bytes from register
	val = self.bus.read_word_data(self.address, reg)
	# return swapped bytes (they come in wrong order)
	return (val >> 8) + ((val & 0xFF) << 8)

def reset(self):
	# To reset the sensor, write 6 to the device I2C address
	self.bus.write_byte(self.address, 6)

def set_addr(self, new_addr):
	# To change the I2C address of the sensor, write a new address
	# (one byte [1..127]) to register 1; the new address will take effect after reset
	self.bus.write_byte_data(self.address, 1, new_addr)
	self.reset()
	self.address = new_addr

def moist(self):
	# To read soil moisture, read 2 bytes from register 0
	return self.get_reg(0)

def temp(self):
	# To read temperature, read 2 bytes from register 5
	return self.get_reg(5)

def light(self):
	# To read light level, start measurement by writing 3 to the
	# device I2C address, wait for 3 seconds, read 2 bytes from register 4
	self.bus.write_byte(self.address, 3)
	time.sleep(1.5)
	return self.get_reg(4)

def __repr__(self):
	return "<Chirp sensor on bus %d, addr %d>" % (self.bus_num, self.address)
if name == "main":
addr = 0x20
if len(sys.argv) == 2:
if sys.argv[1].startswith("0x"):
addr = int(sys.argv[1], 16)
else:
addr = int(sys.argv[1])
chirp = Chirp(1, addr)

print chirp
print "Moisture\tTemperature\tBrightness"
while True:
	print "%d\t%d\t%d" % (chirp.moist(), chirp.temp(), chirp.light())
	time.sleep(1)
At first, I would get:

<Chirp sensor on bus 1, addr 32>
Moisture	Temperature	Brightness
Traceback (most recent call last):
File "chirp.py", line 57, in
print "%d\t%d\t%d" % (chirp.moist(), chirp.temp(), chirp.light())
File "chirp.py", line 29, in moist
return self.get_reg(0)
File "chirp.py", line 12, in get_reg
val = self.bus.read_word_data(self.address, reg)
IOError: [Errno 121] Remote I/O error

Then, I hit the button on the chirp right before I ran the code and started getting this

pi@raspberrypi:~ $ python chirp.py
<Chirp sensor on bus 1, addr 32>
Moisture	Temperature	Brightness
65535	65535	65535
65535	65535	65535

I have checked the reviews and the open issues on the Arduino library from Apollon77 and I even tried adding a 10K pullup on both i2c lines and still get similar results. The only time it seems to work is the first time it runs on arduno code, but then goes back to 65535 readings.

Do you think this is a hardware issue? Do you have any guidance? I have tried this with 2 Chirp!'s and still the same thing.

Miceuz, 2017-08-23:
I have answered your question for plant watering alarm. BTW, where did you get the Chirp?

Closed 2017-08-23.

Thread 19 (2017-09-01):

Gerbers for 2.7.5

bilbolodz, 2017-09-01:
Could you please provide gerber files for 2.7.5 version? It looks that at github there are for 2.7.1. I've tried to generate it myself but kicad gives some error:

`
Date of KiCad version required (or newer): 01/23/17

Full error text:
PARSE_ERROR: Expecting 'clearance, trace_width, via_dia, via_drill, uvia_dia, uvia_drill, or add_net' in input/source
'/home/bilbo/robota/i2c-moisture-sensor/i2c-moist-sensor-pannel.kicad_pcb'
line 132
offset 6
from dsnlexer.cpp : Expecting() : line 369
`

when I'm trying to open i2c-moist-sensor-pannel.kicad_pcb file

2ni, 2018-07-24:
Just clone the whole repo somewhere to your machine, then do "File/Open Project" on kicad and navigate to where you cloned the repo.
Open "i2c-moist-sensor-pannel.pro". You will then see a list of files in kicad itself, and you can double-click on i2c-moist-sensor.kicad_pcb

That worked for me.

Miceuz, 2018-07-24:
You have to use KiCad 5, it has been released last week.

Closed 2019-03-03.

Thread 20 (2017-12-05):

Measuring capacitance: Frequency counting?

DFyson, 2017-12-05:
I noticed you mentioned you had tried timing the period of the sensor in an RC oscillator but didn't work so well because the capacitance was so low thus requiring a combination of very high resistance/fast timer. Have you considered counting the frequency instead? Make an RC oscillator (such as SN74LVC1G132 since it can be disabled) then use the 16bit counter on the microcontroller as a frequency divider and feed that into an interrupt. The linearity, dynamic range and resolution should be much better than the current low-pass filter/ADC method. The output would also be an absolute measurement of the frequency not some relative value thus making it more versatile including other applications.

Miceuz, 2017-12-05:
Yes, counting frequency is another way to measure the capacitance. I did not try to do this, but gate-based oscillators are pretty quirky from my experience, so I am afraid it would be not that stable especially over the temperature and over multiple units. Building a precision oscillator would be a non trivial and costly task. Will have to try this some time.

mindforger, 2017-12-05:
>especially over the temperature

i can support this, had oscillator based solutions drifting like hell, this one works fairly stable even outside

Closed 2017-12-05.

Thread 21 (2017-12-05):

Capacitance values

DFyson, 2017-12-05:
Do you know what the capacitance, in pF, of the probe in air and water? I'm curious to get an idea of its characteristics at both extremes.
Thanks

Miceuz, 2017-12-05:
I don't remember exactly, but something about 50pF

Closed 2017-12-05.

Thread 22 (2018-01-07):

sensor lost address and reading values are not corect ocasionaly - ESP2866 tasmota

roblad, 2018-01-07:
Hi,

Could you look on that threat

https://github.com/Apollon77/I2CSoilMoistureSensor/issues/14

Also haw to block address sensor change when deepsleep and power is from ESP GPIO 3.3V.

And also I am attachin a code from TASMOTA ESP for reviewing potential issue caused sensor problems

>CODE:

`/*
xsns_chirp.ino - CHIRP ambient light sensor support for Sonoff-Tasmota

Copyright (C) 2017  Theo Arends

This program is free software: you can redistribute it and/or modify
it under the terms of the GNU General Public License as published by
the Free Software Foundation, either version 3 of the License, or
(at your option) any later version.

This program is distributed in the hope that it will be useful,
but WITHOUT ANY WARRANTY; without even the implied warranty of
MERCHANTABILITY or FITNESS FOR A PARTICULAR PURPOSE.  See the
GNU General Public License for more details.

You should have received a copy of the GNU General Public License
along with this program.  If not, see <http://www.gnu.org/licenses/>.
*/

#ifdef` USE_I2C
#ifdef USE_CHIRP
//https://github.com/Apollon77/I2CSoilMoistureSensor/blob/master/I2CSoilMoistureSensor.cpp
#include <I2CSoilMoistureSensor.h>

/*********************************************************************************************\
 * CHIRP - Ambient Light Intensity
\*********************************************************************************************/

//#define CHIRP_CONTINUOUS_HIGH_RES_MODE 0x10 // Start measurement at 1lx resolution. Measurement time is approx 120ms.

#define CHIRP_ADDR1         0x20

#define CHIRP_LIGHT_CALIB 32775  //calibrate darknes value for light sensor
#define CHIRP_CAPACITANCE_MIN 220  //calibrate CAPACITANCE min value
#define CHIRP_CAPACITANCE_MAX 750  //c0calibrate CAPACITANCE max value
#define CHIRP_TEMP_CAL 0  //calibrate TEMP value

uint8_t chirpaddr = CHIRP_ADDR1;
uint8_t chirptype = 0;
char chirpstype[7];
uint16_t light = 0;

I2CSoilMoistureSensor sensor(chirpaddr);

uint8_t I2cScan_()
{

  byte error;
  byte address;
  uint8_t address_st;
  byte any = 0;
  uint8_t count = 0;

  for (address = 7; address <= 117; address++) {
    Wire.beginTransmission(address);
    error = Wire.endTransmission();
    if (0 == error) {
      any = 1;
      address_st = address;
    }  else if (4 == error) {
      continue;
      any = 0;
    }
  }
  if (any) {

    return address_st;
  } else {
    return 0;
  }
}

uint16_t chirp_readLux(void)
{
  uint8_t counter = 0;
  sensor.startMeasureLight();

  while (sensor.isBusy() && counter < 50) {

    yield();
    delay(100);
    counter++;
  }

  return sensor.getLight(false);

}

boolean chirp_detect()
{

  uint8_t scan = 0;
  boolean success = false;
  strcpy(chirpstype, "CHIRP");
  byte counter = 0;
  Wire.begin();
  Wire.setClock(40000);
  Wire.setClockStretchLimit(2500);
  scan = I2cScan_();

  if (scan != 0) {

        if (scan != 0 && scan >=7 && scan <= 117 ){

        I2CSoilMoistureSensor:I2CSoilMoistureSensor((uint8_t)scan);

          yield();
          if (sensor.setAddress(chirpaddr,true)) {

            sensor.startMeasureLight();
            success = true;
            chirptype = 1;

          }

        }

      #ifdef CHIRP_CONTINUOUS_HIGH_RES_MODE
        I2cWrite(chirpaddr, CHIRP_CONTINUOUS_HIGH_RES_MODE, 1, 0);
      #endif

    } else if (scan == 0 || scan < 7 || scan > 117 ) {

      snprintf_P(log_data, sizeof(log_data), PSTR("{CHRIP: " "Unknown error"  ": 0x%2x}"), scan);
      AddLog(LOG_LEVEL_INFO);

      success = false;
      chirptype = 0;

    }   else  {

      success = true;
      chirptype = 1;
    }

  if (success == false) {
    success = false;
    chirptype = 0;
    snprintf_P(log_data, sizeof(log_data), PSTR("{CHRIP: " D_I2CSCAN_NO_DEVICES_FOUND ": 0x%2x}"), chirpaddr);
    AddLog(LOG_LEVEL_INFO);

  } else {
    success = true;
    chirptype = 1;
    chirpaddr = CHIRP_ADDR1;
  }

  return success;
}

/*********************************************************************************************\
 * Presentation
\*********************************************************************************************/
#ifdef USE_WEBSERVER
 #ifndef USE_BH1750  // avoid duplicate definition
  const char HTTP_SNS_ILLUMINANCE[] PROGMEM =  "%s{s}%s " D_ILLUMINANCE ": {m}%d %{e}";
 #endif //USE_BH1750
  const char HTTP_SNS_MOISTURE[] PROGMEM = "%s{s}%s " D_MOISTURE ": {m}%s %{e}";
  const char HTTP_SNS_CHIRPTEMP[] PROGMEM = "%s{s}%s " D_TEMPERATURE ": {m}%s &deg;C{e}";
  const char HTTP_SNS_VER[] PROGMEM =  "%s{s}%s Firmware ver.: {m}0x%2x{e}";
#endif // USE_WEBSERVER

const char JSON_SNS_LIGHTMOISTTEMP[] PROGMEM = "%s,\"%s\":{\"" D_LIGHT "\":%d,\"" D_MOISTURE "\":%s,\"" D_TEMPERATURE "\":%s}";

void reader_wait(uint8_t trying)
 {
   uint8_t round = 0;
   while (sensor.isBusy() && round < trying){
   yield();
   delay(20);
   trying++;
   }

 }
static uint8_t count = 0;
void chirp_Show(boolean json)
 {

  if (!I2cDevice(chirpaddr)) {

    chirptype = 0;

      AddLog_P(LOG_LEVEL_DEBUG, PSTR("No CHRIP detected !!!"));

      ExecuteCommandPower(1,7);
      ExecuteCommandPower(1,6);
      yield();
      delay(200);
      ExecuteCommandPower(1,7);
      count++;

      while (sensor.isBusy() && count < 20 ){
        AddLog_P(LOG_LEVEL_DEBUG, PSTR("Waiting for sensor"));
        count++;
        yield();
        delay(50);
      if (count == 18 ) {

        AddLog_P(LOG_LEVEL_DEBUG, PSTR("Traing to redefine sensor"));

        if (chirp_detect()) chirptype = 1;

       }

    }
    count = 0;

  } else {
    count = 0;
    AddLog_P(LOG_LEVEL_DEBUG, PSTR("CHRIP detected."));
    chirpaddr = CHIRP_ADDR1;
    chirptype = 1;
   }

  if (chirptype == 1) {
    char temperature[Settings.flag2.temperature_resolution+3];
    char moisture[Settings.flag2.humidity_resolution+3];
    float readmoisture = 0;
    float readtemperature = 0;
    uint8_t ver = 0;
    uint8_t counter = 0;

    if (!sensor.isBusy() ) {
     ver  = sensor.getVersion();
    } else {

     delay(100);
     ver  = sensor.getVersion();
    }

    do {
      if (!sensor.isBusy() ) {
      readtemperature = sensor.getTemperature();
      } else {
        sensor.getTemperature();
        yield();
        delay(50);

      }

      counter++;

    } while ((readtemperature >850.0 || readtemperature < -500.0) && counter < 8);

    counter = 0;

    do {

    if (!sensor.isBusy() ) {

      readmoisture = sensor.getCapacitance();

    } else {
      sensor.getCapacitance();
      yield();
      delay(50);

    }

      counter++;

    } while ((readmoisture > CHIRP_CAPACITANCE_MAX + 200.0 || readmoisture < CHIRP_CAPACITANCE_MIN - 100.0 ) && counter < 8  );

    counter = 0;

    if (!sensor.isBusy() ) {

        light = chirp_readLux();

      } else {

         do {

              light = sensor.getLight(false);

              counter++;

           } while ((light > CHIRP_LIGHT_CALIB + 1500) && counter < 3);

        counter = 0;

       }

    light = (map((light > CHIRP_LIGHT_CALIB  ? CHIRP_LIGHT_CALIB : light),CHIRP_LIGHT_CALIB,0,0,100));
    readtemperature = ((readtemperature+CHIRP_TEMP_CAL)/10.0);
    readmoisture = (map(readmoisture,CHIRP_CAPACITANCE_MIN,CHIRP_CAPACITANCE_MAX,0,1000)/10.0);
    dtostrfd((readmoisture < 0.0 ? 0.0 : (readmoisture > 99 ? 100.0 : readmoisture)), Settings.flag2.humidity_resolution, moisture);
    dtostrfd((readtemperature > 85.0 ? 85.0 : readtemperature) , Settings.flag2.temperature_resolution-1, temperature);

if (readtemperature >=85.0 || readtemperature < -40.0 || readmoisture >= 99.9 || readmoisture < 1.0 || light > 99.99 || light < 0) {

   sensor.resetSensor();
   yield();
   delay(500);
 }

    if (json) {
       snprintf_P(mqtt_data, sizeof(mqtt_data), JSON_SNS_LIGHTMOISTTEMP, mqtt_data, chirpstype, light, moisture,temperature);

       #ifdef USE_DOMOTICZ
         DomoticzTempHumSensor(temperature, moisture);
         DomoticzSensor(DZ_ILLUMINANCE,light);
       #endif  // USE_DOMOTICZ

  #ifdef USE_WEBSERVER
     } else {
       snprintf_P(mqtt_data, sizeof(mqtt_data), HTTP_SNS_ILLUMINANCE, mqtt_data, chirpstype, light);
       snprintf_P(mqtt_data, sizeof(mqtt_data), HTTP_SNS_MOISTURE, mqtt_data, chirpstype, moisture );
       snprintf_P(mqtt_data, sizeof(mqtt_data), HTTP_SNS_CHIRPTEMP, mqtt_data, chirpstype, temperature);
       snprintf_P(mqtt_data, sizeof(mqtt_data), HTTP_SNS_VER, mqtt_data, chirpstype, ver);

  #endif // USE_WEBSERVER

     }

  }

}

/*********************************************************************************************\
 * Interface
\*********************************************************************************************/

#define XSNS_20

boolean Xsns20(byte function)
{
  boolean result = false;

  if (i2c_flg) {
    switch (function) {
      case FUNC_XSNS_INIT:
        chirp_detect();
        break;
      case FUNC_XSNS_PREP_BEFORE_TELEPERIOD:
        chirp_detect();
        break;
      case FUNC_XSNS_JSON_APPEND:
        chirp_Show(1);
        break;
#ifdef USE_WEBSERVER
      case FUNC_XSNS_WEB_APPEND:
        chirp_Show(0);
        break;
#endif // USE_WEBSERVER
    }
  }

  return result;
}

#endif // USE_CHIRP
#endif // USE_I2C`

Closed 2023-02-25.

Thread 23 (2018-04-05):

Colour code of cable

Rudertier, 2018-04-05:
Hi,
first of all, thanks for the quick delivery. I've ordered one rugged version of the sensor and I'm eager to play around with the device.
Having the rugged version, I can not tell which cable is used for what, and I'm afraid of trying it out on my own.
Any advice?
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

mindforger, 2018-04-05:
pulled from tindie

>Rugged version

Pre-coated version is available since December 2016. The sensor is coated in epoxy resin, cured and additionally protected by adhesive-lined heat shrink. The 1m (3 feet) long cable is pre-soldered. Light sensor is covered by heatshrink, so the light reading will always report total darkness.

The pinout of the rugged version (with white cable):

    RED - VCC
    BLACK - GND
    BLUE or GREEN- SDA
    YELLOW - SCK

Shield is not grounded on the sensor end and must be grounded on the master end.

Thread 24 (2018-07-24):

HW question: Why is there space between capacity and electronics

2ni, 2018-07-24:
Hi
Sorry to bother you... I was just wondering if the sensor needs to be that long. Couldn't it be shortened in total by bringinge the logic and attiny closer to the capacity pad? What is the reason for that space (the length of SENSOR_TRACK on the pcb)?

Miceuz, 2018-07-24:
It's to put electronics further away from soil, no other technical reason.

Closed 2018-07-24.

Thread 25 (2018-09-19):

README.md: Broken link

gmacario, 2018-09-19:
Hello and many thanks for open sourcing the design of this sensor!

FYI: The link in "A complete Open Source logging solution employing a batch of 40 sensors in Crete for tree monitoring" returns Error 404

Miceuz, 2019-03-03:
fixed, thanks

Closed 2019-03-03.

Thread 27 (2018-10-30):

Capacitive measurement

rubengr, 2018-10-30:
Hi,
I bought one chirp, and make another to test diferences.. I read from https://wemakethings.net/chirp/ that "chirp uses capacitive sensing to measure the moisture. 1MHz square wave (system clock is used for that) is output from the chip through a resistor into a big pad that together with the surrounding ground plane forms a parasitic capacitor. "

What i'm see in this code is just a diference between two readings. Can you explain how do you read the capacitance?

```
uint16_t getCapacitance() {
    capMeasurementInProgress = 1;
    uint16_t caph = adcReadChannel(CHANNEL_CAPACITANCE_HIGH);
    uint16_t capl = adcReadChannel(CHANNEL_CAPACITANCE_LOW);
    capMeasurementInProgress = 0;
    return 1023 - (caph - capl);
}
```

Thanks

Miceuz, 2018-10-31:
I am reading the capacitance the same way as described, but the idea is extended a bit further. I am measuring both peak and dip levels of the resulting triangle wave, capacitance estimate is a difference of those two numbers. Note, I don't return a true capacitance value in Farrads, just an arbitrary number that changes with changing capacitance.

rubengr, 2018-10-31:
How do you know in microcontroller if we are on peak or dip level?

Closed 2018-10-31.

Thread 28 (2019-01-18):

Instructions for upgrading from 2.4 to 2.7 firmware?

akutruff, 2019-01-18:
Hi,

I had the sensor running with the Arduino I2C example on firmware 2.4.  (I don't believe 2.4 supported all the registers but it was generally working.) I verified I was getting valid values for capacitance.

I made an attempt to flash to the latest firmware against latest source in this repository.

In a Ubuntu VM, I did:

`
make hex
`

I then copied the main.hex out to windows to do the flash.  (VM's do not like USB programmers apparently.)

I ran:

```
avrdude.exe -c usbtiny -p t44 -U flash:w:main.hex:i -V
avrdude.exe -c usbtiny -p t44 -U hfuse:w:0xDF:m -U lfuse:w:0xAE:m efuse:w:0xF5:m -B 40.96
```
I took those values from the makefile.

I noticed there's a "programmer" folder under src that I did not utilize which makes me believe I missed a step.  Would someone be so kind as to provide guidance? Thanks!

Miceuz, 2019-03-03:
Hi,

You are using -p t44 which suggests you are trying to flash the device based on attiny44 which is really old version, only Chirp plant watering alarm use those nowdays. This firmware is written for attiny441.

Closed 2019-03-03.

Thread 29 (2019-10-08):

Question about the excitation pin

Eriobis, 2019-10-08:
Hi,

I am doing a bluetooth version of your project so I have used your schematics and I was wondering what is exactly the use of the excitation pin ? It seems like I don't see any call to this pin in the code. Can you help me with that ?

Miceuz, 2019-10-08:
Hi there, I have also done a BLE version here - https://github.com/Miceuz/ble-soil-moisture-sensor
Excitation pin is used to excite the sensor. It simply outputs square wave. It is used to output main clock frequency via special registers on AVR.

Eriobis, 2019-10-08:
Wow thanks for your prompt answer. I know I have seen it somewhere in the past, I have designed my board with this pin on a PWM output, but could not find the freq. and duty cycle.

I haven't seen your BLE version of it ! Is it on tindie as well ?

Closed 2019-12-25.

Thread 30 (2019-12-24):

Qwiic connectors

la7dja, 2019-12-24:
Hi

I think it would would be great to have [Qwiic connectors](https://www.sparkfun.com/qwiic) as an option for indoor use. Since it was space on the PCB to add this with only minor changes to the layout, I did that in a [fork](https://github.com/la7dja/i2c-moisture-sensor). [This](https://github.com/la7dja/i2c-moisture-sensor/blob/master/i2c-moist-sensor-qwiic.png) is how looks (without the Qwiic logo which I added later). If it is of interest I could make an pull request, but I don't know how well that will work with Kicad files.

Miceuz, 2019-12-24:
Hi there, good idea! Send me the pull request, I will see how it goes. Thanks!

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

--
Sent from my Android device with K-9 Mail. Please excuse my brevity.

olNick, 2020-07-01:
Hi,
This is the only way I could find to contact you...
Attached is a procedure we used to get a transfer function for the i2c sensor

[M&M_Soil Moisture Sensor Calibration.docx](https://github.com/Miceuz/i2c-moisture-sensor/files/4857624/M.M_Soil.Moisture.Sensor.Calibration.docx)

Hope it helps someone.
Soil used was primarily clay....

regards,
nick

olNick, 2020-07-01:
Sorry,
To save you some reading....

Example:
The calculated dry basis moisture content (MCd) of the soil when a soil moisture sensor reads a capacitance value of 550 corresponds to:
MCd = (0.000001007*5502)+(0.000024885*550)-0.062508722
MCd = 0.2558 or 25.58 %

regards,

Miceuz, 2020-07-18:
Hello,

Thanks a lot for this! Really appreciated!

Can I share it with community? The doc is missing an author/date I would like to attribute you.

olNick, 2020-07-20:
Sure, that's why I sent it...

 As authors,
 Nikos Boretos, George Kazakis, Dany Ghosn, Mediterranean Agronomic
 Institute of Chania (MAICh)

 date 02/2020

 regards,
 Nikos

 On Sat, 18 Jul 2020 00:29:14 -0700, Albertas Mickėnas wrote:
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

Miceuz, 2020-07-20:
Great, thanks!

One more question - were sensors powered from 5V or 3V3?

olNick, 2020-07-20:
3v3

 On Mon, 20 Jul 2020 05:46:25 -0700, Albertas Mickėnas wrote:
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

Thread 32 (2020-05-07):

Cannot change the address with RasPi/Python script.

DIY-Blub, 2020-05-07:
**This entry is primarily for documentation purposes, should the problem occur with others, please write.**

Soil moisture sensor v2.7.8 / version 0x26 (purchase date: April 2020)
Raspberry Pi 1 Model B, Rev 2; "Buster" with latest updates

I wanted to change the I2C address of my 3 purchased sensors with the Raspberry Pi (Python). The sensor query (read out sensor values) per device at 0x20 works. Changing the address was done without error message, but the sensor kept the default address 0x20.

**Python2: used code from**
**https://github.com/ageir/chirp-rpi**
```
wget -O Chirp_ageir.py https://raw.githubusercontent.com/ageir/chirp-rpi/master/chirp.py
chmod +x Chirp_ageir.py
python2 ./Chirp_ageir.py 0x20 set 0x24
```
> Chirp I2C address changed to 0x24

After one (and more) restarts the I2C address is still 0x20.

**https://github.com/JasperWallace/chirp-graphite**
```
wget -O Chirp_JasperWallace.py https://raw.githubusercontent.com/JasperWallace/chirp-graphite/master/chirp.py
chmod +x Chirp_JasperWallace.py
python2 ./Chirp_JasperWallace.py 0x20 --set-address 0x24
```
> version 0x26
> Setting the chirp's i2c address to 0x24
> done

After one (and more) restarts the I2C address is still 0x20.

**https://github.com/Miceuz/i2c-moisture-sensor#raspberry-pi-examples**
Also this simplified script (by JasperWallace) did not change the address, after some adjustments.

**Solution with Arduino**
Only with an Arduino Uno I was able to change the I2C addresses. I used this library:
https://github.com/Apollon77/I2CSoilMoistureSensor

Miceuz, 2020-05-07:
Hi there, thanks for pointing this out. I have updated raspi code on github readme page:

`	def set_addr(self, new_addr):
		# To change the I2C address of the sensor, write a new address
		# (one byte [1..127]) to register 1; the new address will take effect after reset
		self.bus.write_byte_data(self.address, 1, new_addr)
		# second request is required since FW 0x26 to protect agains spurious address changes
		self.bus.write_byte_data(self.address, 1, new_addr)
		self.reset()
		self.address = new_addr
`

DIY-Blub, 2020-05-07:
ok, thanks!

Closed 2020-05-07.

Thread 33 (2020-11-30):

Shorter insert depth

chris-tanner-brightpearl, 2020-11-30:
I am developing a system which requires soil moisture sensing for soil that's only 4cm/5cm deep. The current size of sensor is too long, so I have used the schematic to come up with a PCB for a shorter sensor (see pics). However, I am new to programming the ATtiny441 and I would need to work with someone to help me get it up and running with the programmer source code. I would happily do the work required to put a README up for subsequent developers wanting to do a similar thing, and when the unit is successfully tested, I'll make the PCB layout available.

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

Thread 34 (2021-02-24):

Capacitance 65535

greg10810, 2021-02-24:
Hi,

Recently bought 2 x Plantwateringalarmv2.4 which I have tried to read through I2C using the below setup:

Physical wiring, as per the instructions:
Arduino UNO to Chirp via 6cm jumpers using pin

pin 2 - VCC (3.3v)
pin 3 - SCK / SCL – I2C clock
pin 4 - MOSI / SDA – I2C data
pin 6 - GND

Code as follows:
```
#include <I2CSoilMoistureSensor.h>
#include <Wire.h>

I2CSoilMoistureSensor sensor;

void setup() {
  Wire.begin();
  Serial.begin(9600);

  sensor.begin(); // reset sensor
  delay(1000); // give some time to boot up
  Serial.print("I2C Soil Moisture Sensor Address: ");
  Serial.println(sensor.getAddress(),HEX);
  Serial.print("Sensor Firmware version: ");
  Serial.println(sensor.getVersion(),HEX);
  Serial.println();
}

void loop() {
  while (sensor.isBusy()) delay(50); // available since FW 2.3
  Serial.print("Soil Moisture Capacitance: ");
  Serial.print(sensor.getCapacitance()); //read capacitance register
  Serial.print(", Temperature: ");
  Serial.print(sensor.getTemperature()/(float)10); //temperature register
  Serial.print(", Light: ");
  Serial.println(sensor.getLight(true)); //request light measurement, wait and read light register
  sensor.sleep(); // available since FW 2.3
}
```
The serial output is:
```
Soil Moisture Capacitance: 65535, Temperature: -0.10, Light: 65535
```
with no deviation no matter whether it is in soil or not.

Not sure what my next step should be? Appreciate your assistance.

Closed 2021-02-25.

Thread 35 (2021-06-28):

Temperature Funky above 25°

vrenaville, 2021-06-28:
Hello,

I currently have a rugged version of i2c. It's connected to a RAK 5205.

If Temperature raise above 25° temporature goes funky, 0 c° , 12°c etc ....
when the night comes and the temperature goes below 25c°, it's fine.

My setup:
- RAK 5205 (STM32L Lorawan device)
- Dupont cable connecte (male - male) of 20 cm
- Rugged version connected to 3.3v (on battery)

Do you have this kind of issue in the past ?

Kind regards,

Vincent

mindforger, 2021-06-28:
i noticed that too, on hotter days it seems the value is jumping heavily

vrenaville, 2021-06-28:
I was related to my code I only read the first byte :D

Miceuz, 2021-06-28:
> i noticed that too, on hotter days it seems the value is jumping heavily

Please check if you are reading two bytes from the sensor. Also if sun shines onto the sensor this will make the temperature fluctuate with clouds, shadows, etc covering the sun.

Closed 2021-06-28.

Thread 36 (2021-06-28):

Sleep mode: Rak module require datas

vrenaville, 2021-06-28:
Hello,

With RAK811 module, It support only writing data to registry , not directly on the devise (they told me it's not standard to write directly on the devise)
Do you know if I can write data on the register to set enforce sensor going to sleep ?

Kind regards,

Vincent

Miceuz, 2021-06-28:
Hi @vrenaville what standard are they refering to? I am not aware of this limitation.

No way around it from what I have seen.

One hack you can try is write 0x08 into register 0x08. If I am right, the sensor will go to sleep and come back from it immediately after receving 0x08 and will interpret that as sleep command and go to sleep again.

vrenaville, 2021-06-29:
I have tried to write 0x08 byte on register 0x08, it's accepted, but after the I2C bus and de sensor is completely stuck.
Need to reset the system.

Anyway it's more a Rak issue than from your sensor, but let's wait they improve their tools

Closed 2023-02-25.

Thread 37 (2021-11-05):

ESP32/ MQTT/ LoRa version?

samuk, 2021-11-05:
Hi I realize this is not trivial.

It occurred to me that if you did a version with a ESP32

It could run https://docs.openmqttgateway.com/

And use LoRa mesh (not LoRaWAN) to connect back to the internet: https://meshtastic.discourse.group/t/meshtastic-to-build-environmental-networks/2628/26

Miceuz, 2021-11-10:
Hi @samuk, thanks for suggestions, I will look into that. Note that I have released a LoRaWAN board designed to work with my sensors: https://www.tindie.com/products/miceuz/low-power-lora-i2c-rs485-node/

Miceuz, 2023-02-25:
Also there is an ESP32 based board to hook up the sensor to WiFi and an e-paper display: [https://github.com/Miceuz/paper-wifi/](https://github.com/Miceuz/paper-wifi/)

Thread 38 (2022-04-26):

No response to I2Cdriver command line

kriskeillor, 2022-04-26:
Hello,
I am using the moisture sensor for a smart greenhouse project. To familiarize myself with the I2C interface, I am first attempting to get it working with the [I2CDriver](https://github.com/jamesbowman/i2cdriver) product. Unfortunately, I am not getting any meaningful response; no matter what register I read from, the response is always 0xFF. I have not attempted a write, since it doesn't seem to be working right and I don't want to screw it up.

Here is an example:

```
C:\Users\7hesa>i2ccl COM10 w 0x00 2 r 0x20 2
0xff,0xff

C:\Users\7hesa>i2ccl COM10 w 0x02 2 r 0x20 2
0xff,0xff

C:\Users\7hesa>i2ccl COM10 w 0x04 2 r 0x20 2
0xff,0xff

C:\Users\7hesa>i2ccl COM10 w 0x05 2 r 0x20 2
0xff,0xff

C:\Users\7hesa>i2ccl COM10 w 0x07 2 r 0x20 2
0xff,0xff

C:\Users\7hesa>i2ccl COM10 w 0x09 2 r 0x20 2
0xff,0xff
```

The complete [I2CDriver documentation is available here](https://i2cdriver.com/i2cdriver.pdf). I will try the moisture sensor next with my microcontroller; if that _does_ work, I will bring this issue to the I2CDriver manufacturer. Thanks for reading!

System info: Windows 10 Home 10.0.19043, Build 19043, 64-bit

Miceuz, 2022-04-27:
I don't know where exactly my I2CDriver is, but I think you issue the command wrong, try:
`i2ccl COM10 w 0x20 0x00 r 0x20 2`

First argument in `w` command is the device address, 0x20 being the default address of the sensor. Let me know if it helps.

kriskeillor, 2022-05-08:
@Miceuz, thanks for getting back to me! I just saw this.
I messaged you on Tindie yesterday, feel free to ignore that since we're talking here.

I appreciate the help, its definitely gotten me further, although I'm still a bit confused.

That command seems to be working:

```
C:\WINDOWS\system32>i2ccl COM10 w 0x20 0x00 r 0x20 2
0x00,0xf9

C:\WINDOWS\system32>i2ccl COM10 w 0x20 0x00 r 0x20 2
0x00,0xf7

C:\WINDOWS\system32>i2ccl COM10 w 0x20 0x00 r 0x20 2
0x00,0xf8

/* Now I put my hand around the sensor... */

C:\WINDOWS\system32>i2ccl COM10 w 0x20 0x00 r 0x20 2
0x02,0x26

C:\WINDOWS\system32>i2ccl COM10 w 0x20 0x00 r 0x20 2
0x02,0x23
```

I'm getting variable but consistent (and non-0xFF) readings for the capacitance.

However, I still feel like something is wrong, because when I query the sensor's address, it reports 0xFF - which is obviously not true, since I'm speaking with address 0x20. First I reset and then ask for the address in one line:

```
C:\WINDOWS\system32>i2ccl COM10 w 0x20 0x06

C:\WINDOWS\system32>i2ccl COM10 w 0x20 0x02 r 0x20 1
0xff
```

I also can't seem to _change_ the address.

If it helps, the device version is apparently 0x26:

```
C:\WINDOWS\system32>i2ccl COM10 w 0x20 0x07 r 0x20 1
0x26
```

Thanks again for looking at this problem, I'm new to using i2cdriver so I really appreciate the pointers and the insight about your product.

One more questsion: The [i2cdriver documentation](https://i2cdriver.com/i2cdriver.pdf) has register addresses for writes written in decimal, but you are writing register addresses in hex; do you know if one way is preferred?

Regards,
Kris

Miceuz, 2022-05-08:
Hi Kris,

To change the address you have to perform the register two times in a row, that's my workaround to fight against noise on lines changing address to random number - happened on several occasions.

Regarding the address read - are you allowing enough time for sensor to boot (about 1 second)

I suggest having a look at the sensor library for Arduino environment: https://github.com/Apollon77/I2CSoilMoistureSensor You can the implementation for all the functions there.

kriskeillor, 2022-05-08:
Oh, I didn't see that you have to perform that write twice in a row. Is that documented anywhere?
But, trying it that way did not work either.

I did allow enough time for the boot, yes.

I forgot to mention one thing - the current draw jumps from 5 mA to 10 mA briefly when I send the restart, so I think that command is going through.

Thank you for the library link! I am going to switch from i2ccl to the i2cdriver python module, as its much better documented, to troubleshoot. My project is in C (or Cpp, not currently though), so I appreciate having that library to reference. For the time being python might be quicker to just get something working.

Will report back shortly..!

kriskeillor, 2022-05-08:
I'm having more success with the Python module and libraries and will probably stick to that over i2ccl. It's much better documented both from the official sources, and with open source contributions.

Thanks again for your help @Miceuz!

Closed 2022-05-08.

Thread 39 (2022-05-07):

Mosfet instead of Q2 and Q3 bipolar ?

pit34, 2022-05-07:
Hello,

I ask myself why does Q2 and Q3 are bipolar tranistor and not mosfet ?
There is an explanation of operation here :
https://wemakethings.net/2012/09/26/capacitance_measurement/
But not why bipolar instead of mosfet to discharge the capacitor.

Thanks

kriskeillor, 2022-05-08:
Just a guess from me, but BJTs are cheaper and they do the same thing. That could be the reason.

Miceuz, 2022-05-08:
Err, I don't remember exactly, but I think BJTs I had in my bin were faster to switch than mosfets I had. But in general I had to scrap the idea of discharging as it creates a lot of complication (switching transistor really fast is not simple) and does not give a lot of pros.

Closed 2022-05-08.

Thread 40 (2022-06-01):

Include data format in register address

kriskeillor, 2022-06-01:
The [I2C register map](https://github.com/Miceuz/i2c-moisture-sensor#i2c-protocol) does not define the data format, and the listed examples use different ways of calculating them.

E.g., the [example by Daniel Tamm and Jasper Wallace](https://github.com/Miceuz/i2c-moisture-sensor#raspberry-pi-examples) simply prints the raw registers as Temp (C or F?), Moisture (Relative Humidity?), and Light (Lux?). Meanwhile, the example from _krikk_ (second code block following above anchor link) treats light and moisture as raw values, while temp is divided by ten.

All in all, the data format and unit of the sensor readings needs to be provided in the I2C register map (or somewhere else).

Miceuz, 2023-02-25:
Thanks for pointing this out @kriskeillor

Closed 2023-02-25.

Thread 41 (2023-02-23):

I2C all of a sudden stops working

sebastianneubauer, 2023-02-23:
I bought two i2c-moisture sensors a long time ago in 2015 with version v2.7.1. I never really tried them but now wanted to use them using micropython and an ESP32. It worked like a charm in the beginning, but then all of a sudden the first one stopped working, the micropython exception says:
```
Traceback (most recent call last):
  File "<stdin>", line 1, in <module>
  File "/lib/chirp.py", line 49, in reset
  File "/lib/chirp.py", line 44, in _register_8
OSError: [Errno 19] ENODEV
```
which means: there is not device at this address. Also a i2c scan doesn't return anything back.
So i tried the second old sensor, but also there, after some hours, all of sudden, same problem, sensor seems to become dead.

My setup:
VCC is 3.3V, 2k2 pullup resistors on both SCL and SDA

The micropython code is:
```
>>> from machine import Pin, SoftI2C
>>> import chirp
>>> i2c = SoftI2C(scl=Pin(22), sda=Pin(21))
>>> chirp_sensor = chirp.Chirp(i2c)
>>> chirp_sensor.reset()
Traceback (most recent call last):
  File "<stdin>", line 1, in <module>
  File "/lib/chirp.py", line 49, in reset
  File "/lib/chirp.py", line 44, in _register_8
OSError: [Errno 19] ENODEV
```

What I tried:
* I toggeled SCL low and high several times, same with SDA, no effect
* I pulled "RESET" line low and high several times, the led flashes when pulled high, but no effect

Is there any way to bring them back, or are they dead? Any idea what could have killed them both?

Thanks a lot!

Miceuz, 2023-02-25:
Hi,

2015 was long time ago...

```
commit ba48c0ac055df5c0bccb623ff6fc83b1be8b0bf2
Author: miceuz <mic@wemakethings.net>
Date:   Wed Feb 17 00:17:30 2016 +0200

    Enable BOD finally!
```

Most probably flash is being corrupted due brown out. You should re-flash the sensor with the latest firmware.

sebastianneubauer, 2023-02-25:
Sure, that is a long time ago, but why throwing them away if they are still good (if the are...). I am totally happy to buy a new rugged one, just I somehow would want to be sure that the new one doesn't get bricked again after few hours of runtime because I am doing something wrong.
Any hints or documentation how to flash new firmware?

Miceuz, 2023-02-25:
Sure, no need to throw them away. It's a standard AVR flashing. Are you familiar with that? Are your sensors rugged or plain?

sebastianneubauer, 2023-02-25:
They are both plain, a reason I would anyhow buy a rugged one. Sadly no clue about AVR flashing. Would be awesome if you could throw some pointers my way, e.g. do I need special hardware, where would I connect the sensor, which firmware to use, etc..

Miceuz, 2023-02-26:
Good that you have plain sensors, this means you have access to the programming port.
Here is the pinout for the programming header:
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

It's Sunday and I don't have hardware in my hands to double-check it myself, but these links can help:

This one probably is the most relevant for you:
https://learn.adafruit.com/stand-alone-programming-avrs-using-circuitpython

These are C++ based:
https://github.com/lbernstone/ESP_AVRISP
https://github.com/ESP32-Musings/OTA_update_AVR_using_ESP32

In order for you not to compile the sensor firmware from scratch, you can down download it here: https://gist.github.com/Miceuz/9762f93cad23a95064086fe6c73c575a

I will look into this more next week if you still need it, let me know how it goes.

Miceuz, 2023-02-26:
I have updated the Adafruit example so it has correct chip description to the one used in the sensor, see it below. It "should just work", but as I've said, I can't test it today.

``` python
# SPDX-FileCopyrightText: 2021 ladyada for Adafruit Industries
# SPDX-License-Identifier: MIT

"""
ATtiny441 programming example, be sure you have the '13a wired up so:
  ATtiny441 GND to CircuitPython GND
  ATtiny441 VCC to CircuitPython USB
  Pin 2 -> CircuitPython SCK
  Pin 1 -> CircuitPython MISO
  Pin 0 -> CircuitPython MOSI
  RESET  -> CircuitPython D5 (or change the init() below to change it!)
Drag "main.hex" onto the CircuitPython disk drive, then open REPL!
"""

import board
import busio
import adafruit_avrprog

spi = busio.SPI(board.SCK, board.MOSI, board.MISO)
avrprog = adafruit_avrprog.AVRprog()
avrprog.init(spi, board.D5)

# Each chip has to have a definition so the script knows how to find it

ATtiny441 = {
            "name": "ATtiny441",
            "sig": [0x1E, 0x92, 0x15],
            "flash_size": 4*1024,
            "page_size": 16,
            "fuse_mask": (0xAE, 0xDF, 0xF5, 0x03),
            "clock_speed": 100000,
        }
attiny441 = ATtiny441

def error(err):
    """Helper to print out errors for us and then halt"""
    print("ERROR: " + err)
    avrprog.end()
    while True:
        pass

while input("Ready to GO, type 'G' here to start> ") != "G":
    pass

if not avrprog.verify_sig(attiny441, verbose=True):
    error("Signature read failure")
print("Found", attiny441["name"])

avrprog.write_fuses(attiny441, low=0x7A, high=0xFF)
if not avrprog.verify_fuses(attiny441, low=0x7A, high=0xFF):
    error("Failure verifying fuses!")

print("Programming flash from file")
avrprog.program_file(attiny441, "main.hex", verbose=True, verify=True)

print("Done!")
```

sebastianneubauer, 2023-02-27:
Wohoo, this is just awesome! I found a Atmel AVRIPS MKII, no clue why I have such a thing...but it actually worked and I uploaded your main.hex file to the ATTiny (after figuring out, that I need to power the attiny externally): `avrdude -c avrispmkII -P usb -p t441 -v -U flash:w:main.hex`
...and the sensor is up and running again!! Just it seems, the light measurement always shows 65535, is it the right firmware for the 2.7.1 version? Thank you so much!

Closed 2023-02-25.

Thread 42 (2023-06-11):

Reading capacitance fails on esp32 after sleeping

ethanhjennings, 2023-06-11:
Hi, loving the sensor. I'm using the I2CSoilMoistureSensor library but I can't get seem to get the `sleep()` method to work on an esp32. After sleeping all subsequent returned values are 65535 and I get an i2c error: `requestFrom(): i2cRead returned Error 263` until I do a hard reset by cutting power to the sensor.

Example code with issue:

```cpp
Wire.begin(I2C_SDA_PIN, I2C_SCL_PIN);
Wire.setClock(50000);

I2CSoilMoistureSensor moistureSensor;
moistureSensor.begin(true);

while (true) {
    auto moisture = moistureSensor.getCapacitance();
    Serial.println(moisture);

    moistureSensor.sleep();
    delay(1000);
}
```

Output:
```
258
[  4099][E][Wire.cpp:513] requestFrom(): i2cRead returned Error 263
65535
[  8122][E][Wire.cpp:513] requestFrom(): i2cRead returned Error 263
65535
[ 12145][E][Wire.cpp:513] requestFrom(): i2cRead returned Error 263
65535
[ 16167][E][Wire.cpp:513] requestFrom(): i2cRead returned Error 263
65535
...
```

When I remove the `moistureSensor.sleep()` line and do a hard reset with a power cut it works fine again. Soft rebooting with `moistureSensor.resetSensor()` doesn't work either.

Miceuz, 2023-06-11:
Hi, thanks for the report,

What version of ESP32 are you using? This might be related to https://github.com/espressif/esp-idf/issues/4173 - 13ms max clock stretching limit on older ESP32 chip versions.

ethanhjennings, 2023-06-12:
Hi, I think this is indeed the problem because I'm using a regular ESP32 (not ESP32-S2 or S3). I'm going to try working around this with bit banging or a software i2c library (maybe then switching to using hardware i2c once it's awake).

Closed 2023-06-12.

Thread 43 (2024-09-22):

Multiple sensors measurements

smjacques, 2024-09-22:
Hi,

I bought some sensors to connect them to a ESP32 and test the measurements of multiple sites.

I've changed the code adding two sensors, but the result of the second (sensor2)  is always 'Soil Moisture Capacitance: 65535, Temperature: -0.10, Light: 65535',

I'm afraid I'm missing something here. Is there an example which I could use as a reference for multiple moisture sensors?

My code right now is as follows:

```
#include <I2CSoilMoistureSensor.h>
#include <Wire.h>

// Initialize two sensor objects with different I2C addresses
I2CSoilMoistureSensor sensor1(0x20);  // First sensor with address 0x20
I2CSoilMoistureSensor sensor2(0x21);  // Second sensor with address 0x21

void setup() {
  Wire.begin();
  Serial.begin(9600);

  // Initialize the first sensor
  sensor1.begin();  // reset sensor 1
  delay(1000);      // give some time to boot up
  Serial.print("I2C Soil Moisture Sensor 1 Address: ");
  Serial.println(sensor1.getAddress(), HEX);
  Serial.print("Sensor 1 Firmware version: ");
  Serial.println(sensor1.getVersion(), HEX);
  Serial.println();

  // Initialize the second sensor
  sensor2.begin();  // reset sensor 2
  delay(1000);      // give some time to boot up
  Serial.print("I2C Soil Moisture Sensor 2 Address: ");
  Serial.println(sensor2.getAddress(), HEX);
  Serial.print("Sensor 2 Firmware version: ");
  Serial.println(sensor2.getVersion(), HEX);
  Serial.println();
}

void loop() {
  // Read data from sensor 1
  while (sensor1.isBusy()) delay(50);  // available since FW 2.3
  Serial.print("Sensor 1 - Soil Moisture Capacitance: ");
  Serial.print(sensor1.getCapacitance());
  Serial.print(", Temperature: ");
  Serial.print(sensor1.getTemperature() / (float)10);
  Serial.print(", Light: ");
  Serial.println(sensor1.getLight(true));  // request light measurement, wait and read
  sensor1.sleep();                         // put sensor 1 to sleep

  // Read data from sensor 2
  while (sensor2.isBusy()) delay(50);  // available since FW 2.3
  Serial.print("Sensor 2 - Soil Moisture Capacitance: ");
  Serial.print(sensor2.getCapacitance());
  Serial.print(", Temperature: ");
  Serial.print(sensor2.getTemperature() / (float)10);
  Serial.print(", Light: ");
  Serial.println(sensor2.getLight(true));  // request light measurement, wait and read
  sensor2.sleep();                         // put sensor 2 to sleep

  delay(2000);  // wait a bit before the next reading
}
```

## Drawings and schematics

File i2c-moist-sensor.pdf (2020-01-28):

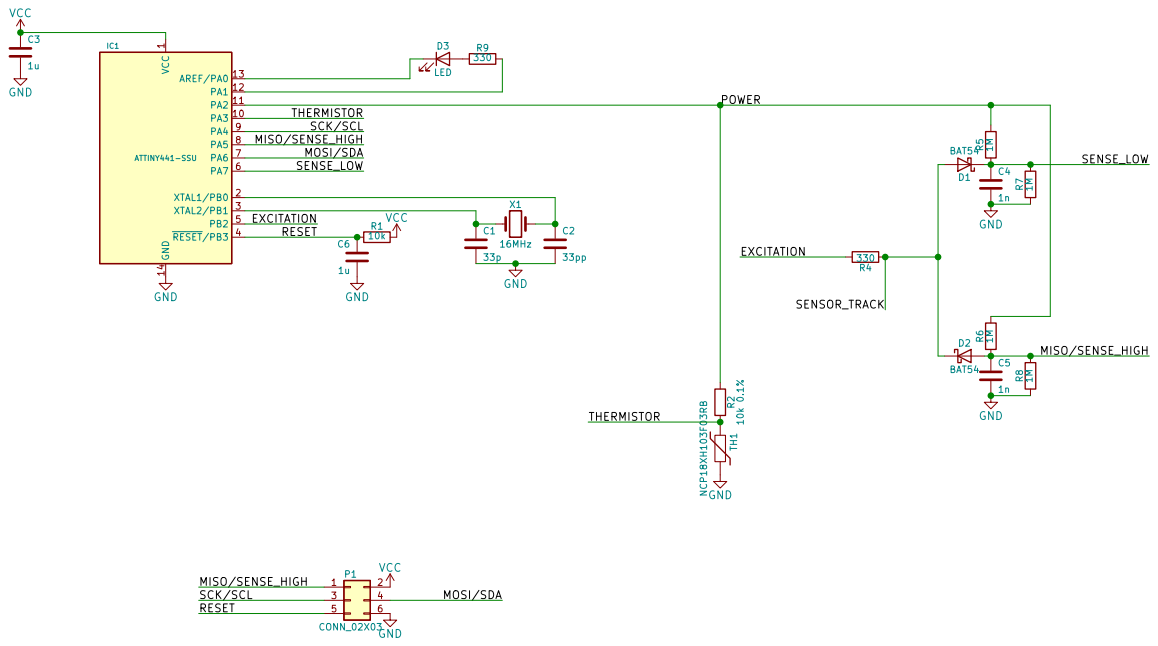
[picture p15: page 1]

THERMISTOR
SCK/SCL

MISO/SENSE_HIGH

EXCITATION
RESET

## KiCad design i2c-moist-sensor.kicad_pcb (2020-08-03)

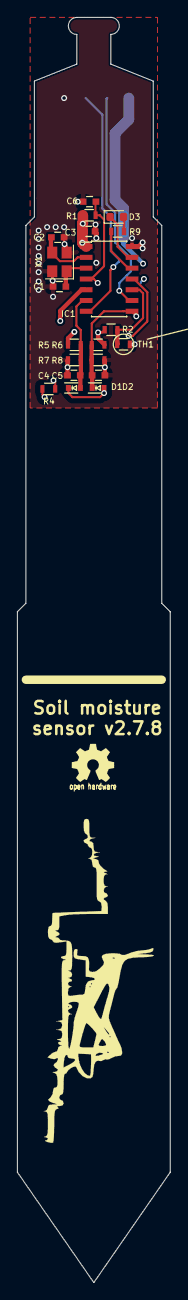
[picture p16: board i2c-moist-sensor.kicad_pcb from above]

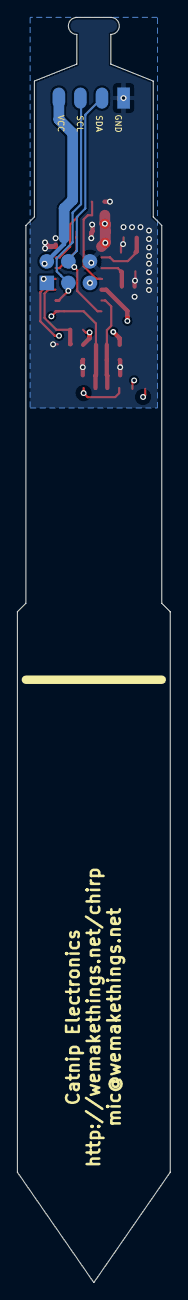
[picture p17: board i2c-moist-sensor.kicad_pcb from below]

Board: 4 copper layers, 18.0 x 149.0 mm, 22 parts (2 on the bottom side), 16 nets.

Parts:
C1: 33p; C_0603
C2: 33pp; C_0603
C3, C6: 1u; C_0603
C4, C5: 1n; C_0603
D1, D2: BAT54; SOD-523
D3: LED; LED_0603_1608Metric
IC1: ATTINY441-SSU; SOIC-14_3.9x8.7mm_Pitch1.27mm
P1: CONN_02X03; Pin_Header_Straight_2x03
P2: CONN_01X04; Pin_Header_Straight_1x04_Pitch2.54mm
R1: 10k; R_0603
R2: 10k 0.1%; R_0603
R4, R9: 330; R_0603
R5, R6, R7, R8: 1M; R_0603
TH1: NCP18XH103F03RB; R_0603
X1: 16MHz; Crystal_SMD_3225-4pin_3.2x2.5mm

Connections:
/EXCITATION: IC1.5, R4.2
/MISO/SENSE_HIGH: C5.1, D2.2, IC1.8, P1.1, R6.1, R8.2
/MOSI/SDA: IC1.7, P1.4, P2.2
/RESET: C6.1, IC1.4, P1.5, R1.1
/SCK/SCL: IC1.9, P1.3, P2.3
/SENSE_LOW: C4.1, D1.1, IC1.6, R5.1, R7.2
/SENSOR_TRACK: D1.2, D2.1, R4.1
/THERMISTOR: IC1.10, R2.2, TH1.1
GND: C1.2, C2.2, C3.2, C4.2, C5.2, C6.2, IC1.14, P1.6, P2.1, R7.1, R8.1, TH1.2, X1.2, X1.4
unnamed: C1.1, IC1.3, X1.1
unnamed: C2.1, IC1.2, X1.3
unnamed: D3.1, IC1.13
unnamed: D3.2, R9.1
unnamed: IC1.11, R2.1, R5.2, R6.2
unnamed: IC1.12, R9.2
VCC: C3.1, IC1.1, P1.2, P2.4, R1.2

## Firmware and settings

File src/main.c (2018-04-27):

#include <inttypes.h>
#include <avr/io.h>
#include <util/delay.h>
#include <avr/interrupt.h>
#include <avr/eeprom.h>
//#include <avr/wdt.h>
#include <avr/sleep.h>
#include "thermistor.h"
#include "twi.h"

#define FIRMWARE_VERSION 0x26 //2.6

#define LED_K PA1
#define LED_A PA0
#define LED_DDR DDRA
#define LED_PORT PORTA
#define POWER_DDR DDRA
#define POWER_PORT PORTA
#define POWER_PIN PA2

#define CHANNEL_THERMISTOR 3
#define CHANNEL_CAPACITANCE_HIGH 5
#define CHANNEL_CAPACITANCE_LOW 7
#define CHANNEL_CHIP_TEMP 0b00001100

#define TWI_GET_CAPACITANCE     0x00
#define TWI_SET_ADDRESS         0x01
#define TWI_GET_ADDRESS         0x02
#define TWI_MEASURE_LIGHT       0x03
#define TWI_GET_LIGHT           0x04
#define TWI_GET_TEMPERATURE     0x05
#define TWI_RESET               0x06
#define TWI_GET_VERSION         0x07
#define TWI_SLEEP               0x08
#define TWI_GET_BUSY            0x09

#define I2C_ADDRESS_EEPROM_LOCATION (uint8_t*)0x01
#define I2C_ADDRESS_DEFAULT         0x20

inline static void ledSetup(){
    LED_DDR |= _BV(LED_A) | _BV(LED_K);
    LED_PORT &= ~_BV(LED_A);
    LED_PORT &= ~_BV(LED_K);
}

inline static void ledOn() {
    LED_PORT |= _BV(LED_A);
}

inline static void ledOff() {
    LED_PORT &= ~_BV(LED_A);
}

inline static void powerOn() {
	POWER_DDR |= _BV(POWER_PIN);
	POWER_PORT |= _BV(POWER_PIN);
}

inline static void powerOff() {
	POWER_PORT &= ~_BV(POWER_PIN);
}

inline static void ledToggle() {
    LED_PORT ^= _BV(LED_A);
}

inline static void adcSetup() {
    ADCSRA = _BV(ADEN) | _BV(ADPS2) | _BV(ADPS1) | _BV(ADPS0);
    ADCSRA |= _BV(ADIE);
    ADMUXB = 0;
}

uint8_t adcInProgress = 0;

inline static void sleepWhileADC() {
    adcInProgress = 1;
    while(adcInProgress) {
	    set_sleep_mode(SLEEP_MODE_ADC);
	    sleep_mode();
    }
}

ISR(ADC_vect) { 
	adcInProgress = 0;
    //nothing, just wake up
}

uint16_t adcReadChannel(uint8_t channel) {
    ADMUXA = channel;
    ADCSRA |= _BV(ADSC);
    sleepWhileADC();
   // loop_until_bit_is_clear(ADCSRA, ADSC);
    uint16_t ret = ADC;
    return ret;
}

uint8_t tempMeasurementInProgress = 0;

int getTemperature() {
    tempMeasurementInProgress = 1;
    uint16_t thermistor = adcReadChannel(CHANNEL_THERMISTOR);
    long temp = thermistorLsbToTemperature(thermistor);
    tempMeasurementInProgress = 0;
    return (int)temp;
}

#define isTemperatureMeasurementInProgress() tempMeasurementInProgress

uint8_t capMeasurementInProgress = 0;

uint16_t getCapacitance() {
    capMeasurementInProgress = 1;
    uint16_t caph = adcReadChannel(CHANNEL_CAPACITANCE_HIGH);
    uint16_t capl = adcReadChannel(CHANNEL_CAPACITANCE_LOW);
    capMeasurementInProgress = 0;
    return 1023 - (caph - capl);
}

#define isCapacitanceMeasurementInProgress() capMeasurementInProgress 
//--------------------- light measurement --------------------

volatile uint16_t lightCounter = 0;
volatile uint8_t lightCycleOver = 1;

#define PCINT1 1

static inline void stopLightMeasurement() {
    GIMSK &= ~_BV(PCIE0);
    TCCR1B = 0;
    PCMSK0 &= ~_BV(PCINT1);
    TIMSK1 &= ~_BV(TOIE1);

    lightCycleOver = 1;
}

ISR(PCINT0_vect) {
    GIMSK &= ~_BV(PCIE0);//disable pin change interrupts
    TCCR1B = 0;          //stop timer
    lightCounter = TCNT1;
    
    stopLightMeasurement();
}

ISR(TIMER1_OVF_vect) {
    lightCounter = 65535;
    stopLightMeasurement();
}

static inline uint16_t getLight() {
    PRR &= ~_BV(PRTIM1);

    TIMSK1 |= _BV(TOIE1);               //enable timer overflow interrupt
    
    LED_DDR |= _BV(LED_A) | _BV(LED_K);    //forward bias the LED
    LED_PORT &= ~_BV(LED_K);               //flash it to discharge the PN junction capacitance
    LED_PORT |= _BV(LED_A);

    LED_PORT |= _BV(LED_K);                //reverse bias LED to charge capacitance in it
    LED_PORT &= ~_BV(LED_A);
    _delay_us(100);
    LED_DDR &= ~_BV(LED_K);                //make Cathode input
    LED_PORT &= ~(_BV(LED_A) | _BV(LED_K));//disable pullups
    
    TCNT1 = 0;
    TCCR1A = 0;
    TCCR1B = _BV(CS10) | _BV(CS11);                 //start timer1 with prescaler clk/64
    
    PCMSK0 |= _BV(PCINT1);              //enable pin change interrupt on LED_K
    GIMSK |= _BV(PCIE0); 

    lightCycleOver = 0;

    set_sleep_mode(SLEEP_MODE_IDLE);
    sleep_mode();
}


static inline uint8_t isLightMeasurementInProgress() {
    return !lightCycleOver;
}

inline static void wdt_disable() {
    MCUSR = 0;
    CCP = 0xD8;
    WDTCSR &= ~_BV(WDE);
}

inline static void wdt_enable() {
    CCP = 0xD8;
    WDTCSR = _BV(WDE);
}

#define reset() wdt_enable(); while(1) {}

uint16_t currCapacitance = 0;
int temperature = 0;

uint8_t setAddressActive = 0;
uint8_t addressCandidate = 0;

static inline void loopSensorMode() {
    while(1) {
        if(twiDataInReceiveBuffer()) {
            uint8_t usiRx = twiReceiveByte();

            if(TWI_SET_ADDRESS != usiRx) {
                setAddressActive = 0;
                ledOff();
            }

            if(TWI_GET_CAPACITANCE == usiRx) {
                twiTransmitByte(currCapacitance >> 8);
                twiTransmitByte(currCapacitance &0x00FF);
                currCapacitance = getCapacitance();
            } else if(TWI_SET_ADDRESS == usiRx) {
                uint8_t newAddress = twiReceiveByte();

                if(twiIsValidAddress(newAddress)) {
                    if(0 == setAddressActive) {
                        ledOn();
                        setAddressActive = 1;
                        addressCandidate = newAddress;
                    } else {
                        if(newAddress == addressCandidate) {
                            eeprom_write_byte((uint8_t*)0x01, newAddress);
                        }
                        setAddressActive = 0;
                        ledOff();
                    }
                }

            } else if(TWI_GET_ADDRESS == usiRx) {
                uint8_t newAddress = eeprom_read_byte((uint8_t*) 0x01);
                twiTransmitByte(newAddress);

            } else if(TWI_MEASURE_LIGHT == usiRx) {
                if(!isLightMeasurementInProgress()) {
                    getLight();
                }

            } else if(TWI_GET_LIGHT == usiRx) {
                GIMSK &= ~_BV(PCIE0);//disable pin change interrupts
                TCCR1B = 0;          //stop timer
                
                twiTransmitByte(lightCounter >> 8);
                twiTransmitByte(lightCounter & 0x00FF);

                GIMSK |= _BV(PCIE0); 
                TCCR1B = _BV(CS10) | _BV(CS11);                 //start timer1 with prescaler clk/64
            } else if(TWI_GET_TEMPERATURE == usiRx) {
                twiTransmitByte(temperature >> 8);
                twiTransmitByte(temperature & 0x00FF);
                temperature = getTemperature();
            } else if(TWI_RESET == usiRx) {
                reset();

            } else if(TWI_GET_VERSION == usiRx) {
                twiTransmitByte(FIRMWARE_VERSION);
            } else if(TWI_SLEEP == usiRx) {
            	powerOff();
                set_sleep_mode(SLEEP_MODE_PWR_DOWN);
                sleep_mode();
                powerOn();
            } else if(TWI_GET_BUSY == usiRx) {
                twiTransmitByte(isCapacitanceMeasurementInProgress() || 
                                isTemperatureMeasurementInProgress() || 
                                isLightMeasurementInProgress());
            }
        }
    }
}

static inline void setupPowerSaving() {
    PRR = _BV(PRTIM0) | _BV(PRTIM1) | _BV(PRTIM2) | _BV(PRSPI) | _BV(PRUSART0) | _BV(PRUSART1); //shut down everything we don't use
    ACSR0A = _BV(ACD0); //disable comparators
    ACSR1A = _BV(ACD1);
    DIDR0 = _BV(ADC3D) | _BV(ADC5D) | _BV(ADC7D);//disable input buffers for analog pins
}

int main (void) {
    wdt_disable();

    uint8_t address = eeprom_read_byte(I2C_ADDRESS_EEPROM_LOCATION);
    if(!twiIsValidAddress(address)) {
        address = I2C_ADDRESS_DEFAULT;
    }

    setupPowerSaving();
    ledSetup();
    adcSetup();
    powerOn();
    sei();

    ledOn();
    _delay_ms(100);
    temperature = getTemperature();
    currCapacitance = getCapacitance();
    //we do it two times because the first reading after reset might be off...
    temperature = getTemperature();
    currCapacitance = getCapacitance();
    ledOff();

    twiSetup(address);    
    loopSensorMode();
}

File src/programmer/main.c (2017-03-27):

#include "firmware.h"
#include <avr/io.h>
#include <util/delay.h>
#include <avr/pgmspace.h>
#include "usi_i2c_master.h"

#define ISP_OUT   PORTA
#define ISP_IN    PINA
#define ISP_DDR   DDRA
#define ISP_RST   PA0
#define ISP_MOSI  PA6
#define ISP_MISO  PA5
#define ISP_SCK   PA4
#define LED_K PB0 
#define LED_A PB1

#define CLOCK_T_320us   60
#define TIMERVALUE      TCNT0
#define clockInit()  TCCR0B = (1 << CS01) | (1 << CS00);

#define PAGE_SIZE 8 //words

unsigned char sck_sw_delay = 1;

void inline ledOn() {
  DDRB |= _BV(LED_A) | _BV(LED_K); //forward bias the LED
  PORTB &= ~_BV(LED_K);            //flash it to discharge the PN junction capacitance
  PORTB |= _BV(LED_A);  
}

void inline ledOff() {
  DDRB &= ~(_BV(LED_A) | _BV(LED_K)); //make pins inputs
  PORTB &= ~(_BV(LED_A) | _BV(LED_K));//disable pullups
}


static inline void clockWait(uint8_t time) {

    uint8_t i;
    for (i = 0; i < time; i++) {
        uint8_t starttime = TIMERVALUE;
        while ((uint8_t) (TIMERVALUE - starttime) < CLOCK_T_320us) {
        }
    }
}

static inline void ispDelay() {
    uint8_t starttime = TIMERVALUE;
    while ((uint8_t) (TIMERVALUE - starttime) < sck_sw_delay) {
    }
}

unsigned char ispTransmit(unsigned char data) {
    unsigned char rec_byte = 0;
    unsigned char i;
    for (i = 0; i < 8; i++) {
        /* set MSB to MOSI-pin */
        if ((data & 0x80) != 0) {
            ISP_OUT |= (1 << ISP_MOSI); /* MOSI high */
        } else {
            ISP_OUT &= ~(1 << ISP_MOSI); /* MOSI low */
        }
        /* shift to next bit */
        data = data << 1;

        /* receive data */
        rec_byte = rec_byte << 1;
        if ((ISP_IN & (1 << ISP_MISO)) != 0) {
            rec_byte++;
        }

        /* pulse SCK */
        ISP_OUT |= (1 << ISP_SCK); /* SCK high */
        ispDelay();
        ISP_OUT &= ~(1 << ISP_SCK); /* SCK low */
        ispDelay();
    }

    return rec_byte;
}

static inline unsigned char ispEnterProgrammingMode() {
    unsigned char check;
    unsigned char retry = 32;

    while (retry--) {
        ispTransmit(0xAC);
        ispTransmit(0x53);
        check = ispTransmit(0);
        ispTransmit(0);

        if (check == 0x53) {
            return 0;
        }

        /* pulse RST */
        ispDelay();
        ISP_OUT |= (1 << ISP_RST); /* RST high */
        ispDelay();
        ISP_OUT &= ~(1 << ISP_RST); /* RST low */
        ispDelay();
    }
    return 1; /* error: device dosn't answer */
}

static inline void ispConnect() {
    ISP_DDR = 0;
    ISP_OUT = 0;
    /* all ISP pins are inputs before */
    /* now set output pins */
    ISP_DDR |= (1 << ISP_RST) | (1 << ISP_SCK) | (1 << ISP_MOSI);

    /* reset device */
    ISP_OUT &= ~(1 << ISP_RST); /* RST low */
    ISP_OUT &= ~(1 << ISP_SCK); /* SCK low */

    /* positive reset pulse > 2 SCK (target) */
    ispDelay();
    ISP_OUT |= (1 << ISP_RST); /* RST high */
    ispDelay();
    ISP_OUT &= ~(1 << ISP_RST); /* RST low */
}

void ispCommand(unsigned char instruction, unsigned char a1, unsigned char a2, unsigned char a3) {
    ispTransmit(instruction);
    ispTransmit(a1);
    ispTransmit(a2);
    ispTransmit(a3);    
}

static inline unsigned char isPageBoundary(unsigned int i) {
    return i > 0 && 0 == (i + 1) % (PAGE_SIZE);
}

static inline void setFuses(unsigned char low, unsigned char high, unsigned char extended) {
    ispCommand(0xAC, 0xA0, 0x00, low);
    clockWait(30);
    ispCommand(0xAC, 0xA8, 0x00, high);
    clockWait(30);
    ispCommand(0xAC, 0xA4, 0x00, extended);
    clockWait(30);
}

static inline void chipErase() {
    ispCommand(0xAC, 0x80, 00, 00);
    clockWait(30);
}

static inline void flashFirmware() {
    unsigned int i;
    for(i = 0; i < FIRMWARE_WORD_COUNT; i++) {
        if(i % 2) ledOn();
        else ledOff();
        unsigned int word = pgm_read_word(&(firmware[i]));
        ispCommand(0x40, i >> 8, i & 0xFF, word & 0xFF);
        ispCommand(0x48, i >> 8, i & 0xFF, word >> 8);
        if(isPageBoundary(i)) {
            ispCommand(0x4C, i >> 8, i & 0xFF, 0x00);
            clockWait(15);
        }
    }
    
    if(!isPageBoundary(i - 1)) {
        ispCommand(0x4C, (i -1) >> 8, (i - 1) & 0xFF, 0x00);
    }
}

static inline void blink(unsigned int count) {
        int i = 0;
        for(i = 0; i < count; i++) {
                ledOn();
                _delay_ms(50);
                ledOff();
                _delay_ms(50);
        }
}

volatile unsigned char incomming[] = {0x20 << 1 | 0x01, 0x00, 0x00};

static inline char testFirmwareVersionPasses() {
    char getFwVersionCommand[] = {0x20 << 1, 0x07};
    incomming[1] = 0;
    USI_I2C_Master_Start_Transmission(getFwVersionCommand, 2);
    USI_I2C_Master_Start_Transmission(incomming, 2);
    return 0x23 == incomming[1];
}

static inline char testCapacitanceWithinLimits() {
    char readCapacitanceCommand[] = {0x20 << 1, 0x00};
    USI_I2C_Master_Start_Transmission(readCapacitanceCommand, 2);
    incomming[1] = 0;
    incomming[2] = 0;
    _delay_ms(1);
    USI_I2C_Master_Start_Transmission(incomming, 3);
    unsigned int capacitance = ((((unsigned int) incomming[1]) << 8) | incomming[2]);
    return capacitance > 180 && capacitance < 300;
} 

static inline char testTempWithinLimits() {
    char readCapacitanceCommand[] = {0x20 << 1, 0x05};
    USI_I2C_Master_Start_Transmission(readCapacitanceCommand, 2);
    incomming[1] = 0;
    incomming[2] = 0;
    _delay_ms(1);
    USI_I2C_Master_Start_Transmission(incomming, 3);
    unsigned int temp = ((((unsigned int) incomming[1]) << 8) | incomming[2]);
    return temp > 100 && temp < 400;
} 

static inline void blinkError() {
    ledOn();
    _delay_ms(2000);
    ledOff();
}

static inline unsigned char testsPass() {
    return testFirmwareVersionPasses() &&
           testTempWithinLimits() &&
           testCapacitanceWithinLimits();
}

void main(void) {
        clockInit();
        
        while(1) {
                ispConnect();
                
                _delay_ms(100);
                while(ispEnterProgrammingMode()) {
                    ispConnect();
                    _delay_ms(500);
                    ledOn();
                    _delay_ms(500);
                    ledOff();
                }
                
                setFuses(0xAE, 0xDF, 0xF5);
                chipErase();
                flashFirmware();
                ledOff();

                ISP_OUT |= (1 << ISP_RST); //release reset
                _delay_ms(300);
                
                ISP_DDR = 0;
                ISP_OUT = 0;
                
                if(!testsPass()) {
                    blinkError();
                } else {
                    blink(30);
                }
                USICR = 0;
        }
}

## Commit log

2015-06-16 Fix led name
    [i2c-moist-sensor-bom.ods]
2015-10-25 New eeschema libs are new. Move TH1 and R4 OUT of the soil. Minimize stray capacitance where it matters
    [i2c-moist-sensor.kicad_pcb, i2c-moist-sensor.sch]
2015-10-26 Fix LED footprint according to the datasheet, add data for the bom to schematics
    [i2c-moist-sensor.kicad_pcb, i2c-moist-sensor.sch]
2015-10-26 Sleep to conserve the power
2015-10-26 Change xtal load cap value
    [i2c-moist-sensor.sch]
2015-10-26 Put the new version to the pannel
    [i2c-moist-sensor-pannel.kicad_pcb, i2c-moist-sensor.kicad_pcb]
2015-10-26 Add gerber
    [i2c-moist-sensor-pannel-B.Cu.gbr, i2c-moist-sensor-pannel-B.Mask.gbr, i2c-moist-sensor-pannel-B.SilkS.gbr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]
2015-10-26 Updated BOM
    [i2c-moist-sensor-bom.xls]
2015-10-27 Mark temperature measurement also
2016-02-16 Add extended fuse with proper BOD settings to standalone programming/testing rig firmware
2016-03-16 A couple of small fixes - do some effort to avoid off readings after reset, also perform a proper capacitance calculation
    [main.c]
2017-03-27 Fix address validation so that it is compliant with NXP spec
    [twi.c]
2017-03-27 Now we have a more up to date compiler and avr-libc, so no need for hacks. Also run ADC slower to possibly increase accuracy
2017-03-27 Remove sharp corners so that heatshrink lays nicer
    [i2c-moist-sensor-pannel-B.Cu.gbr, i2c-moist-sensor-pannel-B.Mask.gbr, i2c-moist-sensor-pannel-B.SilkS.gbr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]
2017-04-19 Changes for the next release - stronger vias connecting to the sensor pad, align caps for better coating convenience, use silkscreen as cover for problematic vias
    [i2c-moist-sensor-pannel.kicad_pcb]
2017-07-12 Add a 3d rendering of the sensor
2017-08-02 Power thermistor and moisture sensing circuitry from a pin rather than directly so lower the power consumption
    [i2c-moist-sensor-pannel.kicad_pcb, i2c-moist-sensor.kicad_pcb, i2c-moist-sensor.sch]
2017-11-28 Firmware 2.4 - turn power on/off to resistive dividers
2017-12-08 Fix flops that prevent compiling on avr-gcc 7.2.0
    [main.c]
2017-12-08 Add the latest gerbers
    [.drl, i2c-moist-sensor-pannel-B.Cu.gbr, i2c-moist-sensor-pannel-B.Mask.gbr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]
2017-12-08 Add heatshrink to BOM
    [i2c-moist-sensor-bom.ods]
2017-12-08 Shuffle stuff around
    [i2c-moist-sensor-pannel.kicad_pcb]
2017-12-08 Update revision number
    [i2c-moist-sensor.sch]
2017-12-08 Add STEP file, not zip file
    [i2c-moist-sensor.stp]
2018-02-26 Don't receive TWI interrupts we are not interested in
2018-02-26 Sleep more and wait for the ADC conversion to finish as TWI interrupts can wake up the sensor from ADC sleep
2018-04-27 Make wait for i2c byte timeout to avoid hanging. The new address change order - you have to issue the address change command two times for it to take effect. Bump software version to 2.6
    [main.c, twi.c]
2018-07-02 removed via's in earth
    [i2c-moist-sensor.kicad_pcb]
2018-07-02 4 layers, B.Cu -> In2.Cu
    [i2c-moist-sensor.kicad_pcb]
2018-07-03 In1.Cu - sensing pad
    [i2c-moist-sensor.kicad_pcb]
2018-07-03 add 1mm, F.Cu GND -> In1.Cu
    [i2c-moist-sensor.kicad_pcb]
2018-07-03 added gerbers for four layer pcb
    [i2c-moist-sensor-B.Cu.gbr, i2c-moist-sensor-B.Mask.gbr, i2c-moist-sensor-B.SilkS.gbr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]
2018-07-05 fixed unconnected
    [i2c-moist-sensor.kicad_pcb]
2018-07-14 new header, connected SENSE-HIGH, RESET, GND
    [i2c-moist-sensor.kicad_pcb]
2018-07-20 new header
    [i2c-moist-sensor.kicad_pcb]
2018-07-20 changed crystal to SMD 3225
    [i2c-moist-sensor-2018-07-20-11-33-21.sch, i2c-moist-sensor-2018-07-20-13-07-41.sch, i2c-moist-sensor.kicad_pcb]
2018-07-20 generated new gerbers
    [i2c-moist-sensor-B.Cu.gbr, i2c-moist-sensor-B.Mask.gbr, i2c-moist-sensor-B.SilkS.gbr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]
2018-07-24 created and added 3D models, generated STEP file
    [CRY_SMD3225.STEP, User Library-CAP_SMD-1.STEP, User Library-LTST-C190GKT.STEP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]
2018-07-24 Move stuff around, shorten traces to crystal, fix silkscreen, add cable connector pads, send files for manufacturing
    [i2c-moist-sensor-B.Cu.gbr, i2c-moist-sensor-B.Mask.gbr, i2c-moist-sensor-B.SilkS.gbr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]
2018-12-05 Change shape of the board to accomodate narrower heatshrink, recover schematics from kicad version rescue hell
    [i2c-moist-sensor-2018-07-20-11-33-21.sch, i2c-moist-sensor-2018-07-20-13-07-41.sch, i2c-moist-sensor-2018-07-24-14-05-28.sch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]
2018-12-30 Add picture and 3d model of the new shape of the sensor
2018-12-30 Add connector illustration
2019-10-08 New kicad library order
    [i2c-moist-sensor.sch]
2019-10-08 Chase kicad format updates, add 3d step file of the sensor
    [i2c-moist-sensor.kicad_pcb, i2c-moist-sensor.step]
2019-10-08 add 3dmodels
    [User Library-CAP_SMD-1.STEP, User Library-Crystal HC49_US-SM.STEP, User Library-LTST-C190GKT.STEP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]
2019-10-08 One more kicad kiss
    [i2c-moist-sensor.sch]
2020-01-28 Add schematics PDF
2020-07-22 Add calibration document
2020-08-03 Add silkscreen for temp sensor
    [i2c-moist-sensor.kicad_pcb]
2020-10-04 Gerbers are generated, remove them
    [i2c-moist-sensor-B.Cu.gbr, i2c-moist-sensor-B.Mask.gbr, i2c-moist-sensor-B.SilkS.gbr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]
2020-10-04 Ignore new style kicad backups
2020-10-04 Remove manufacturing files as they are generated
    [i2c-moist-sensor-bom.xls]
